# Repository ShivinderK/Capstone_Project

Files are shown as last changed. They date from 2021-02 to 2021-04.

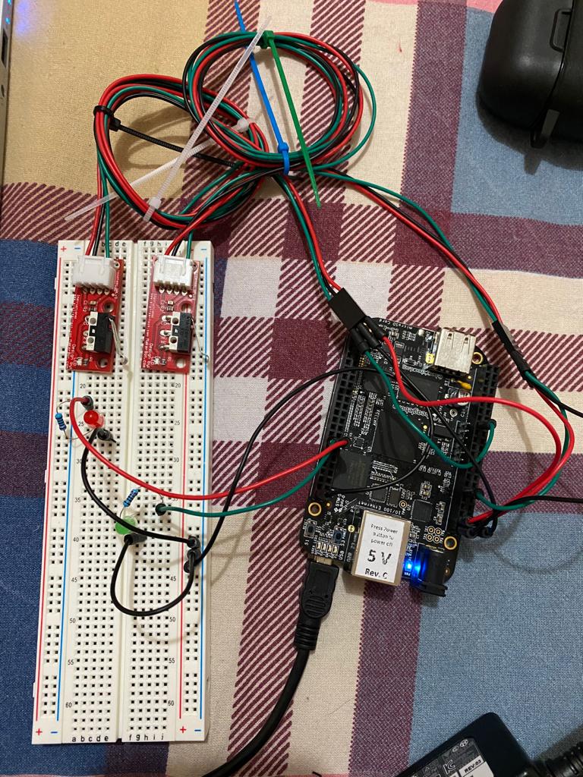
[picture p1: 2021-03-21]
Interfacing of Beaglebone black with Limit switch/Hardware connections.jpeg

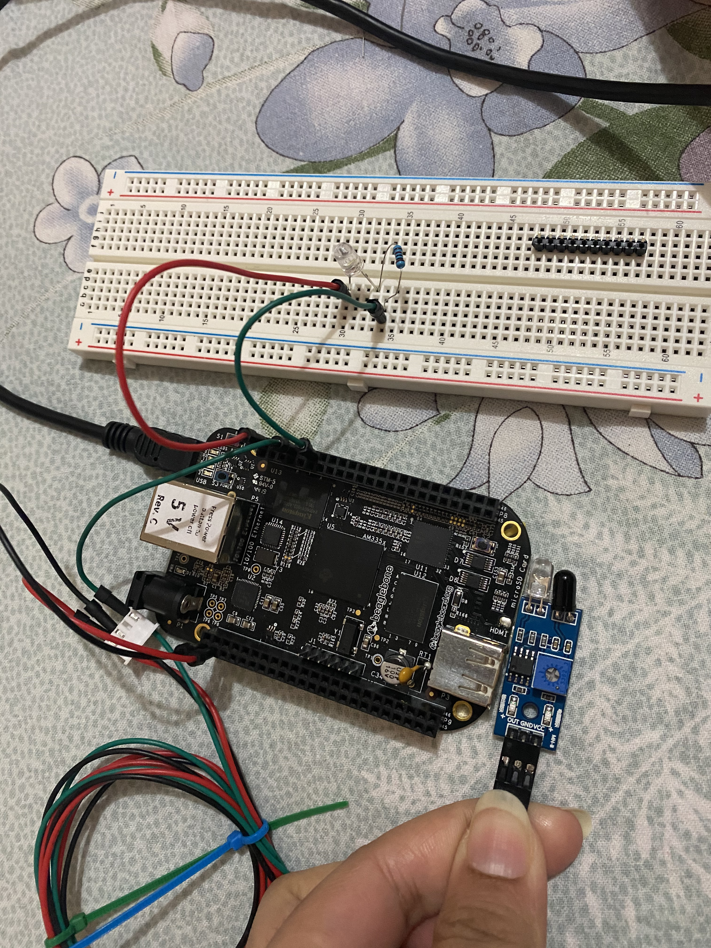
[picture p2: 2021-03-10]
interfacing PIR sensor 1/IMG-0328.jpg

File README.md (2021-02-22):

_# Capstone_Project
Group Members: Shivinder Kaur (C0751078), Dawinder Kaur (C0765505), Manpreet Kaur (C0757604), Raghav Chopra (C0772292), Gopikrishnan K. Gopalkrishnan (C0753811)

Embedded Systems and design is one of the most growing industry and at a very fast pace. We as Embedded engineers always try to make something innovative and useful for end user as an embedded application. In semester 4 , we are challenged to showcase our skills which we have learnt in past 3 semesters into a reality.  We have learnt various skills such as Working with software platform i.e eclipse ide for C  and C++. In this semester we will do coding with these platform for our final project. The another software tool which we will use in this semester is cloud computing services such as AWS or Thingspeak. Apart from that, in subjects 3025 and 3014 we worked with arduino, beaglebone black for our class assignments. That gave us an exposure to interface between these components and all the requirement to work with these MCU's. While working in labs in semster 1 and 2 we worked with basics of electronics such as power measurement , voltage regulators , ADC and DAC’ And therefore we can use that experience to implement in our capstone project.

Our project "IOT based smart garage door opener" is the upgradation of the currently used garage door openers accessed through the web. In our project an alternate garage door access provision via a keypad and LCD screen is provided, along with that key security features like sending notifications via GSM Module, Use of IR Proximity sensors to prevent any accidents and the usage of a buzzer in case any obstacle comes in between and the door remains open more than a set time period. In addition to all of the upgradations we are storing the opening and closing timings of the garage door on the cloud which will enable to user to find out any security breach. 

Added features will always demand extra components. This is the list of all the hardware components and their use in our project:

1. Beaglebone black: The main MCU in our project, all the components in our project are connected directly or indirectly to the unit.
2. Arduino Uno: Act as slave MCU in our project,  Added to our project to provide an alternate garage door access via Keypad and LCD screen.
3. L298N Motor driver: Used to drive the DC motor and to control its direction of rotation.
4. DC 6V Gear Motor: Used to open and close the garage door.
5. Microswitches: To detect the opening and closing of the door.
6. ESP32 Wifi Module: To access Wifi, since Beaglebone Board doesnt have an inbuilt wifi module.
7. Logic Level controller: To change the voltage level from 5V to 3.3V and viceversa for supplying different components.
8. IR Sensor: To detect any obstacle when the garage door is closing.
9. Buzzer: To alert the user in case an obstacle is detected or the garage door remains open for more than set time.
10.Push Button: To acknowledge the Buzzor.
11.GSM Module: To notify the user about the door opening and closing.
12.Keypad Matrix: To enter password for garage opening and enable garage closing via a key.
13.LCD Display: To display user entered password via special character and to display messages to user.
14.Power Adapter: To provide supply to Beaglebone black.
15.16GB Sd Card: To flash latest image of debian.
16.LED Light assorted kit: To notify open/close status of the garage door.
17.PCB Board: To solder all the components together
18.Resistors: To limit the flow of current or divide voltage through the circuit.
19.Spark Fun Beginners kit: For using various capacitors, diodes and other components we may need in the project.  
20.Silicon Hookup wires: To connect sensors, buzzer and other components to the main unit.
HARDWARE TESTING OF COMPONENTS
Hardware testing of components plays a vital role in the overall success of the project. Testing of components is done via measuring, taking readings, performing operations on the hardware to check its performance for the desired outputs.
Hardware testing is usually more detailed and thorough than verification. Testing is needed to ensure that every component of a system is operating as it should, and that the system is performing exactly in accordance with the specific local requirements.
In our capstone following are the components which we have tested:
Arduino Uno Board: Arduino Uno is a microcontroller board based on the  ATmega328P. It has 14 digital input/output pins (of which 6 can be used as PWM Outputs), 6 analog inputs, a 16MHZ quartz crystal , a USB connection, a power jack, an ICSP header and a reset button. It contains everything needed to support the microcontroller; simply connect it to a a computer with a USB cable power it with a AC-to DC adapter or battery to get started.
IR Sensor:R Sensors are Infrared sensors. It uses the Infrared light to detect if there is any obstacle in between the area. It has IR led which will reflect the light and the component next to IR led is a Photodiode which will receive reflected light if there is any obstacle present. The blue nob is the Potentiometer  on IR sensor , which can be adjusted to select the range. There are two small indicators on the sensor ; one indicates the sensor is on and the other one will light up when the receiver photodiode will receive light from the obstacle.The IR sensor gives digital output only in the form of 0 and 1.
IR sensor 						Arduino
Ground 							Ground
VCC								5V
Output Pin						Digital Output Pin 2
Lcd display:In our Capstone project we are using LCD to display messages for user. We are using 20*4 LCD display. It is very important to test display before we implement it in our final project. For this we checked the clear visual of characters displayed on the screen. We checked special characters on the display as well. Interfacing of Arduino with LCD was done to conduct the testing.
LCD Display 						Arduino
Ground 							Ground
VCC								5V
SDA								A4
SCL								A5
Buzzer:
Buzzer ia a device which will produce signalling noise to alert user whenever the door remains open for long time. Also, whenever there is an obstacle in between the door while closing. We are using CLT1036 buzzer which requires 4-8 v DC supply to operate. We connected our buzzer directly to Arduino and tested its performance.
Buzzer	 						Arduino
Ground 							Ground
VCC								Pin 13
L298N motor driver
The L298N is a dual H- Bridge motor driver which allows speed and direction control of two dc motors at the same time. The module can drive the DC motor that have voltages between 5 and 35V, with a peak current up to 2A. In our project we will use only one port for Dc motor.
DC motor is rotary mechanism that will convert the direct current to a mechanical movement, in our case it will open and close the garage door.
L298N	 						          Arduino
Ground 							Ground
VCC								5V
Input V								Battery 12V					
	DC Motor 						L298N
   Terminal 1						Out 1
	Terminal 2						Out 2
  GSM Module
  GSM module is used to send SMS to user in particular situations. It will be interfaced with Arduino Uno. The testing was done via connecting GSM Module to Arduino Uno

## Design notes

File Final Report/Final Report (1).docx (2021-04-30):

A Project Report

On

IOT Based Smart Garage Door Opener

Submitted by:

Dawinder Kaur (C0765505)

Manpreet Kaur (C0757604)

Shivinder Kaur (C0751078)

Gopi Krishnan K. GopalaKrishnan (C0753811)

Raghav Chopra (C0772292)

Under the guidance of

Dr. Mike Aleshams

ESE-4009 Embedded System Design Project

(January 2021 - April 2021 )

Abstract

This major project is all about the embedded systems and its applications in the real world with the help of beaglebone black and arduino software. As a result of enhanced civilization and modernization, human nature demands more comfort in their life. The person seeks ways to do things easily which saves time. So thus, the automatic gates are one of the inventions that brings comfort and ease in their daily life. Before as well people used garage doors to provide security to their vehicles but nowadays, in this modern world people need more security so that an unknown person will not access the garage door. That's why, IOT based garage doors are available now which secures the doors more accurately and people can save their entrance and exit times on the cloud along with the personal details of the vehicles. The owner will get the notification through the GSM module if any unknown person will try to open the garage door. The PIR sensor detects the vehicle at the time of opening the door and also finds the obstacle at the time of closing the door.

Acknowledgements

In our efforts towards the realization of the project work, we have drawn on the guidance of many people and we would like to express my heartfelt gratitude to all the people who helped in fulfilling the accomplishment of this project.

We would like to express my deep gratitude to Michael Vourakes, Director, Lambton College in Toronto for providing us an opportunity to study and in providing infrastructure and resources required to complete this project.

We also would like to extend our gratitude to Dr. Mike Aleshams for the unconditional support and coordination to make this project a success. We also would like to thank him for sparing time and providing necessary information patiently and providing efficient tips for debugging. His constant motivation and inspiration have led to successful completion of the project.

We also extend Dr. Takis Zourntos, Course Coordinator for Embedded System Design for critical advice and guidance without which the project would not have been possible. We also extend our gratitude to all other Professors of Lambton College in Toronto for their guidance and support in compiling the project and those people who have helped us knowingly and unknowingly for the completion of the project.

Lambton College in Toronto is a great place to study and work, largely because of supporting faculty members. Thanks to all my colleagues for supporting and encouraging our idea.

TABLE OF CONTENTS Page No.

List of Figures 5

Chapter I - Introduction 8

Overview 8

Problem statement 8

Goal and Objective 8

Scope of project 9

Outcomes and Benefits 12

Facilities and Resources 12

Procedure and Methodology 13

Chapter II - Literature Review 14

Chapter III - Requirement and Analysis 16

Hardware and Software 16

Hardware and Software Tools 17

Power Requirement 17

Block Diagram 18

Chapter IV - Design 21

Project Schematic 21

Knowing Hardware 22

Knowing Hardware and Software Tools 30

Cloud service - Thingspeak 34

PCB Design 36

Chapter V - Implementation and Test 39

Flow chart 39

Interfacing with BBB 43

Coding 66

Final Model 70

Chapter VI - Evaluation 72

Introduction 72

Minimum Requirements 72

Troubleshooting 72

Chapter VII - Conclusion 74

Future Work 74

Chapter VIII - User’s Guide 75

References 79

List of Figures

Figure No. | Description
2.1 | Circuit Diagram of Existing Project
2.2 | Block Diagram of Existing Project
3.1 | Block Diagram of Final
4.1 | Schematic Design of Project
4.2 | Beaglebone Black
4.3 | Pin Configuration of Beaglebone Black
4.4 | Arduino UNO
4.5 | IR Proximity Sensor
4.6 | SIM800L Module GSM Module
4.7 | Buzzer
4.8 | 4x4 Matrix Keypad
4.9 | L298N DC Motor Driver
4.10 | Limit Switches
4.11 | 20x4 LCD Display
4.12 | ESP32 Wifi Module
4.13 | Push Button
4.14 | DC 6V Gear Motor
4.15 | LED Lights
4.16 | Logic Level Controller
4.17 | Digital Multimeter
4.18 | Breadboard
4.19 | Jumper Wires
4.20 | General Purpose Tools
4.21 | Soldering Kit
4.22 | Thingspeak channel created for project
4.23 | Setting channel for read and write API
4.24 | Visualization in Thingspeak
4.25 | Easy EDA Introduction window
4.26 | Circuit Schematic Drawing
4.27 | Search window for components
4.28 | PCB Design for Project
5.1 | Flowchart using Webpage
5.2 | Flowchart using LCD and Keypad
5.3 | Interfacing BBB with IR Sensors
5.4 | Interfacing ESP32 with BBB
5.5 | Interfacing BBB with Motor Driver L298N and DC Motor
5.6 | Interfacing BBB with Limit switches
5.7 | Interfacing BBB with Buzzer
5.8 | Interfacing BBB with Push Button
5.9 | Interfacing BBB with Arduino
5.10 | Interfacing Arduino with LCD Display
5.11 | Interfacing Arduino with Keypad
5.12 | Interfacing Arduino with GSM Module
5.13 | Connections of Hardware Components
5.14 | Backview of the project
5.15 | Final model of our project
8.1 | Beaglebone with Adapter
8.2(a) | Uploading Code to the Wifi Module
8.2(b) | Connecting Wifi to the Wifi Module
8.3(c) | Wifi getting connected
8.3(d) | ESP32 Web Server
8.4 | Keypad and LCD

Chapter I

Introduction

Overview

This project is the modification and upgradation in the existing project of Smart garage door opener. In this project, we have used a GSM module, Beaglebone black, Arduino, Cloud service and other hardware components. The purpose of this project is to provide more security to the garage doors and also we have used one cloud service i.e., Thingspeak which saves the details of the vehicle and the status of opening and closing the door.

It has one most important feature that is also related to security, if someone tries to access the garage door by entering the password multiple times, then a notification will be sent to the owner of the garage in order to avoid any mishappening.

Problem Statement

The door plays an important role in home security. So, providing a secured garage door system for houses has become necessary. This project deals with opening and closing of garage doors by giving commands through webpage. The principle of operation behind the working of this project lies in the functioning of NodeMCU ESP12E. It works as a wifi module that provides access to the webpage through a local web server. The webpage displays one button to open and close the garage door using a relay module and DC motor. It has some limitations like the microcontroller NodeMCU ESP12E can only be used as a wifi module and also it is not an IOT based project. It has no security features. Because of all these limitations, we have decided to modify the existing project with new features like cloud service and additional security features.

Goal and Objectives

Goal

Make an IOT based smart garage system with GSM and cloud based technology running with Linux kernel by the end of April 2021.

Objective

- Connecting a host processor Beaglebone black to one of the available cloud services like thingspeak, Aws and so on.
- Interface the IR sensor which will help us to know if any obstacle blocks the garage door at the time of opening and closing.
- Configuring the wifi capabilities to connect cloud service.
- Send a notification if an unknown person tries to access the door by entering the wrong password three times.

Scope of the project

Deliverable

- This project will access the garage door via webpage as well as keypad and LCD for opening and closing.
- Transfer all the data to the cloud service.
- Generate a PCB design for the project.
- Intimate about the door activity via SMS services through cloud services.
- Plug and Play the project that is the smart garage door should function without the help of any other device or laptop to execute the codes written and get the exact output.

Milestones

S.no. | Task Title | Start Date | End Date | Person In-charge
1 | Project Proposal | 27-jan-2021 | 12-feb-2021
2 | Deciding and ordering hardware components | 13-feb-2021 | 15-feb-2021 | Gopi Krishnan
3 | Testing hardware components Part 1 | 16-feb-2021 | 22-feb-2021 | Raghav Chopra
4 | Testing hardware components Part 2 | 16-feb-2021 | 22-feb-2021 | Manpreet Kaur
5 | Designing Schematic Diagram | 23-feb-2021 | 26-feb-2021 | Shivinder Kaur
6 | Interfacing BBB with IR sensor (to detect the status of garage) | 27-feb-2021 | 5-march-2021 | Dawinder Kaur
7 | Interfacing WIFI Module ESP32 with BBB | 27-feb-2021 | 5-march-2021 | Shivinder Kaur
8 | HTML coding for web page | 6-march-2021 | 10-march-2021 | Dawinder Kaur
9 | Interfacing BBB with Motor Driver L298N and connecting it to DC motor | 11-march-2021 | 15-march-2021 | Gopi Krishnan
10 | Interfacing of Limit Switch with BBB | 15-march-2021 | 19-march-2021 | Raghav Chopra
11 | Interfacing BBB with IR sensor (to detect obstacle) | 15-march-2021 | 19-march-2021 | Manpreet Kaur
12 | Interfacing Buzzer with BBB | 20-march-2021 | 26-march-2021 | Raghav Chopra
13 | Interfacing Button with BBB | 23-march-2021 | 28-march-2021 | Shivinder Kaur
14 | Interfacing Cloud services with ESP32 | 28-march-2021 | 2-april-2021 | Dawinder Kaur
15 | Interfacing Arduino with BBB | 28-march-2021 | 2-april-2011 | Gopi krishnan
16 | Interfacing LCD display with arduino | 3-april-2021 | 9-april-2021 | Manpreet Kaur
17 | Connecting Keypad with arduino | 3-april-2021 | 9-april-2021 | Raghav Chopra
18 | Interfacing Arduino with GSM Module | 10-april-2021 | 16-april-2021 | Gopi Krishnan
19 | PCB design using particular software | 10-april-2021 | 16-april-2021 | Manpreet Kaur
20 | Zero PCB Implementation Part 1 | 17-april-2021 | 23-april-2021 | Shivinder Kaur
21 | Zero PCB implementation Part 2 | 17-april-2021 | 23-april-2021 | Dawinder Kaur
22 | Final Report | 24-april-2021 | 25-april-2021
23 | Final Presentation | 27-april-2021 | 28-april-2021

Limitations

- When the user enters the wrong password to open the garage door more than 3 times then the owner will get notification but the LCD and keypad does not get locked. The user still can access them.
- If the owner forgets the password then there is no option to reset the password directly using keypad and LCD.

Outcomes and Benefits

- This project is powered up with the power adapter so no need to worry about the power unless there is no electricity in the house.
- If due to some reason the owner will not be able to open the door by using a keypad then he/she can access it by using cloud service.
- It could be an upgrade to the existing project.
- It will help to save the details of the door status at the time of opening and closing to the cloud service which the owner can review later on.

Facilities and Resources

Laboratory

- As we have our classes online so we were not able to access the Embedded Systems Lab of our college. So we created a miniature laboratory at our own places to do all the work on the project.
- Soldering stations, Digital Multimeters, Linux or PuTTy installed PCs and all the other required components were available at our homemade labs.

Intellectual Resources

- Data sheets of GSM module, Beaglebone black, Arduino and other hardware components.
- Forums of Beaglebone, Element14 and components101 communities.
- Exploring Beaglebone tools and techniques for building with Embedded Linux (Second Edition) from Derek Molloy.

Procedure and Methodology

- Getting the hardware requirements ready and ordered for the project sideways testing the components and understanding their working as they keep on arriving.
- Install and update the devices such as the Beaglebone with the latest image OS in order to get to use some of the latest features available in terms of device trees and drivers.
- Upon the getting the testing results positive and approved move and design the circuit schematic using software like EasyEDA, Fritzing, KiCad or Eagle, etc.
- Installation of various libraries which will make our task of controlling the pins of Beaglebone easy and communication between peripherals and sensor simpler.
- Keeping the schematic in mind gets the connection ready for the interfacing in part as this will help us to know in case we go wrong or if the system is not working at some points.
- We start with the interfacing of BBB with IR to detect the status of the garage.
- To make the data available on the cloud service we need to establish a wired connection between ESP 32 and BBB and send the appropriate data to the cloud and make it visible to the user.
- After that, interface all the hardware components with each other.
- At the end of all the interfacing we will integrate them and check if we get the desired functionality as mentioned in the proposal.
- In order to minimize the amount of wiring we must generate the PCB design. The PCB could be designed with the same software that we may have used in making the schematic on the software in step iii).
- Solder the devices on the PCB and test for the final demonstration of the project.
- Make the project run in such a way that when powered on the program should auto-run without the help of any sort of connection with laptop or any external devices.

Chapter II

Literature Review

Wifi Based Smart Garage Door Opener

This project deals with opening and closing of garage doors by giving commands through webpage. The principle of operation behind the working of this project lies in the functioning of NodeMCU ESP12E. It works as a wifi module that provides access to the webpage through a local web server. The webpage displays one button to open and close the garage door using a relay module and DC motor.

Circuit Diagram:

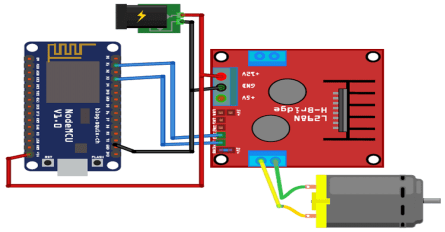
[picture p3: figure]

Fig.2.1 Circuit Diagram of Existing Project

Block Diagram:

Fig.2.2 Block Diagram of Existing Project

Working:

The working principle of the project is giving commands through a web page displaying a message about garage door “open and close” status. So when the garage door is closed then the message is displayed as “The Garage Door is closed” and the OPEN button is shown on the screen. The Node MCU ESP12E is programmed accordingly using an Arduino IDE by providing a wifi username and password in code. When the user opens the webpage using the IP address from the serial monitor window the web page opens. When the user clicks on the open or close button the message goes to Node MCU which passes the command to the relay module to rotate the DC motor “clockwise or anticlockwise” which helps in opening and closing the garage door.

CHAPTER III

Requirement and Analysis

Hardware and Software

In this project, we are using hardware and software components along with the hardware and software tools so that we will get the proper output. Below, we have attached the list of hardware and software components and also the tools which we have used in our project.

Hardware components :

1. Arduino Uno
2. Beaglebone Black
3. ESP32 wifi module
4. 4x4 matrix keypad
5. 20x4 LCD Display
6. SIM800L Module GSM/GPRS
7. Power Supply
8. IR proximity sensors
9. Buzzer Electronic alarm
10. Push button
11. MicroLimit switch
12. DC Motor
13. L298N Motor Driver
14. SanDisk SD card 16 gb
15. Logic level controllers
16. PCB Board
17. 5mm LED light assorted kit

Software components:

1. Latest image of debian for beaglebone black
2. Amazon Web Services or ThingSpeak or any other free IoT service provider.
3. C/C++ Programing
4. HTML programming

Hardware and Software Tools

Hardware Tools:

1. Multimeter
2. Breadboard
3. Jumper Wires/ Silicon hook up wires
4. General purpose tools
5. Soldering Kit
6. Laptop or host machine

Software Tools:

1. EasyEDA for PCB and schematic design
2. Eclipse IDE for programming
3. PuTTy software
4. Compiler
5. Debugger
6. Assembler
7. Arduino IDE

Power Requirement

We are providing a sufficient amount of power to get the system working and performing all the tasks. Thus, looking at the requirement for our project we find that we have two major power consuming components which are:

1. Beaglebone Black – 2 A @ 5V

2. Arduino based GSM Shield – 2 A @ 5V

So, estimated power requirements for full product assembly will be approximately 4V @ 4A for smooth and interrupt free operation. As most of the hardware components that we want to use for the project and when we look at the pin out diagram of the same, we realise that we can power them up directly from the Beaglebone thus no extra power supply is required for them.

Block Diagram

For the final solution, we will implement the project as we have discussed in the second solution but with some modifications. We will add a GSM module in the project which will be connected with Arduino. This module will be used for sending notifications to the user via SMS in case the door remains open. Also, the keypad will be used to enter a password to open the door but for closing the door we will just need to press enter key.

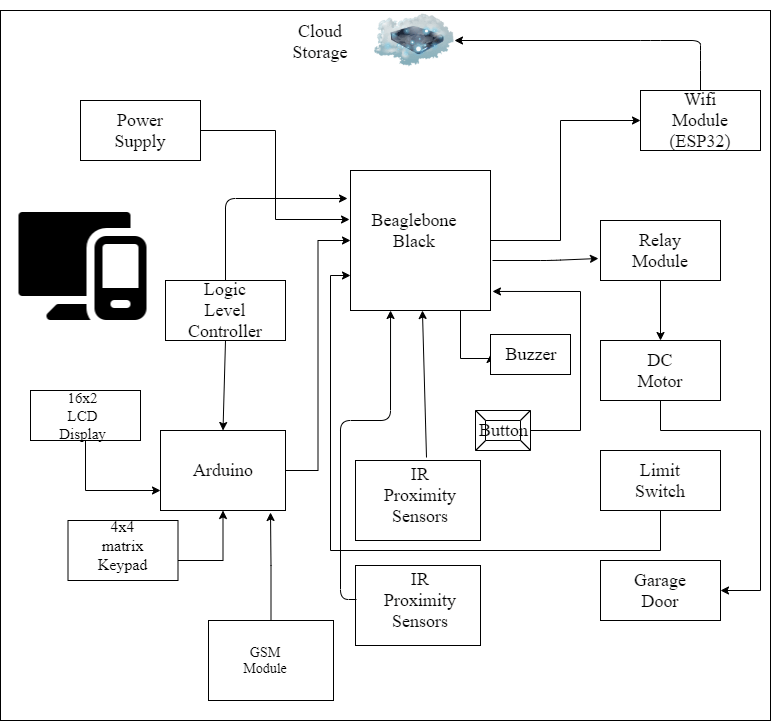
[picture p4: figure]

Fig 3.1 Block diagram for the final solution

Features:

- Using Beaglebone as the main microcontroller which has high processing speed and more advanced features.
- Using Arduino as a slave device which is supporting the alternate solution of opening and closing the door.
- The project is IoT based as it is connected to Wifi for cloud storage.
- IR Proximity Sensors will be used to detect any object in between the garage door while closing.
- Use of a buzzer if the door remains open for a long time.
- Also a GSM module has been added which will notify the owner via SMS that the door remained open.

Chapter IV

Design

Project Schematic

Fig 4.1. Schematic Design for the project

Above figure shows the schematic capture for the project which will help us wire the same. To draw the schematic, we use EasyEDA software. EasyEDA is a free open-source platform and is best suited for beginners in schematic capture. As we can see in this schematic how the hardware components get connected with the Beaglebone black. All Beaglebone Boards have the same pin configuration. At the later stage of the project, we used this schematic and converted it into the PCB Layout which we can use to get PCB manufactured for the project. Before moving on further let us first discuss and know the hardware in detail which will help us in programming the system and reason for our connection.

Knowing Hardware

Beaglebone Black

The Beaglebone black is a low cost, open hardware and expandable computer launched by a community of developers from Texas Instruments. It consists of a large amount of input and output pins and also it has on board interfaces which enables the devices to connect smoothly with the beaglebone black.

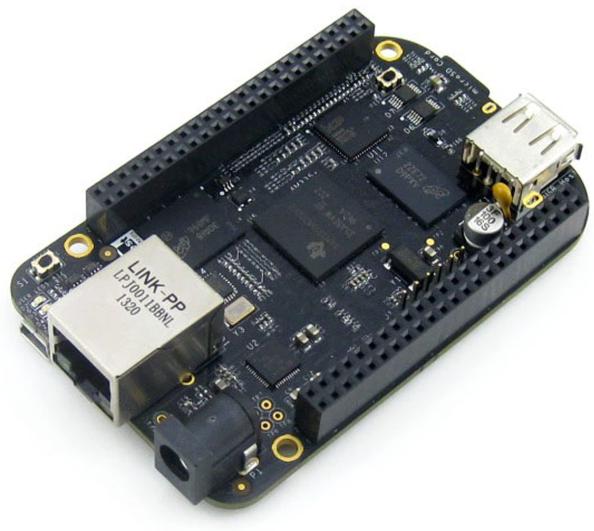
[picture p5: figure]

Fig 4.2. Beaglebone Black

Beaglebone Black has so many technical specifications and also it has a large number of GPIO I/O pins. It is an open source hardware technology which gives options to the manufacturer to integrate ARM technology for developing cloned beaglebone development boards and also it provides options to install a wide range of android and linux based operating systems.

Pin configuration of Beaglebone Black:

It has two headers P8 and P9 and both headers have 46 pins. Also, it has GPIO pins as well which we can use at the time of interfacing with other hardware components.

Fig 4.3. Pin Configuration of Beaglebone Black

Arduino Uno

The Arduino UNO is an open source microcontroller board which is based on the microchip ATmega328P (for Arduino UNO R3) or microchip ATmega4809 (for Arduino UNO wifi R2) microcontroller by Atmel and was the first USB powered board developed by Arduino.It contains everything needed to support the microcontroller, simply connect it to a computer with a USB cable or power it with a AC-to-DC adapter or battery to get started.

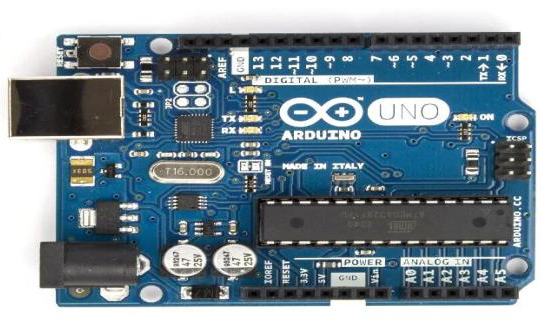
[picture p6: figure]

Fig 4.4. Arduino UNO

IR Proximity Sensors:

In our project we are using IR sensor EK1254 which is an obstacle detecting sensor. We will place this sensor on the garage door to avoid any collision while the door will be closing. This module can be directly connected to beaglebone black. It can be connected to both 5V and 3.3 V microcontrollers.

The module does not require to contact the object to detect it; it detects within the distance between 2-30 cm. They are capable of detecting motion in presence or absence of the light almost with the same reliability.

The figure shows the IR sensor. It has a transmitter and receiver to detect any obstacle.

Fig 4.5. IR Proximity Sensors

SIM800L Module GSM GPRS

In our project we want to notify users via SMS, if the garage door remains open for a long time and sends an alert message. For this purpose we will use the SIM800L GSM module. It is a small miniature cellular module which allows for GPRS transmission, sending and receiving messages. Here are the specifications of this module:

- Quad-Band GSM 850/900/1800 / 1900MHz
- GPRS multi-slot class 12/10
- GPRS mobile station class B
- GSM 2/2 +FM frequency between 76 MHz and 109 kHz adjustable by step 50AT command set support (3GPP TS 27.007, 27.005 and augmented by SIMCOM AT)
- Class 4 (2W at 850 / 900MHz)
- Class 1 (1 W at 1800 / 1900MHz)
- Serial interface
- SIM card interface 3 V / 1.8 V

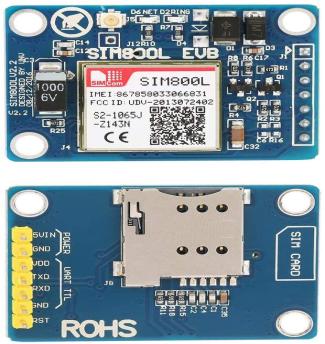
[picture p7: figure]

Fig 4.6. SIM800L Module GSM GPRS

Buzzer

To alert the user about obstacles we need an actuator , for this purpose we are using a buzzer and this will be connected to beaglebone black. For our project we are using Cylewet CLT1036. It requires <25mA and 4-8 voltage to operate.

Fig 4.7. Buzzer

4X4 Matrix Keypad

Matrix keypads are the kind of keypads you see on cell phones, calculators, microwaves ovens, door locks, etc. Membrane keypads are made of a thin, flexible membrane material. They do come in many sizes 4×3, 4×4, 4×1 etc. Regardless of their size, they all work in the same way.Let’s take 4×4 keypad as an example. It has a total of 16 keys. Beneath each key is a special membrane switchAll these membrane switches are connected to each other with a conductive trace underneath the pad forming a matrix of 4×4 grid.

Fig.4.8. 4X4 Matrix Keypad

L298N DC Motor Driver

L298N Motor Driver interface with beaglebone black which controls both speed and spinning direction of two DC motors.

This can be achieved by combining these two techniques.

- PWM (Pulse Width Modulation) – For controlling speed
- H-Bridge – For controlling rotation direction

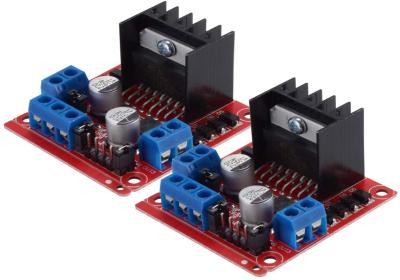
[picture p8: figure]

Fig.4.9 L298N DC Motor Driver

Limit Switches

The micro limit switch, or micro switch, is a limit switch commonly found on control circuits. In our project we will use these switches to sense motion and to open and close the door with the actuators.In our project we will use PChero part number iS008 switch.

Fig.4.10 Limit Switches

20X4 LCD Display

In our project we will notify the user via lcd display whenever the user will enter the wrong password. To display certain messages to notify the user for access granted or access denied. For our project we are using 20*4 LCD display module. It can show 20 characters in one row which is perfect to display a small message to the user. This specific product includes a serial interface adapter and therefore no need to buy an extra adapter. Less I/O ports are occupied, only four - VCC, GND, SDA (serial data line), SCL (serial clock line). and thus no connections are required.

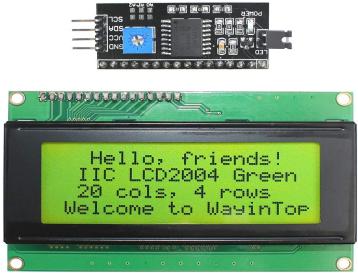
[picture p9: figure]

Fig.4.11 20X4 LCD Display

ESP32 Wifi Module

As we have discussed that our project is going to be IOT based, for that we need internet connection. As we are using beaglebone black, which doesn’t have any internal wifi module. Therefore, we will use a separate Wifi Module for internet connectivity. For this purpose we are using the ESP32 wifi module. This module can be used for low power sensors networks. ESP32 also integrates a wealth of peripherals, including capacitive touch sensors, Hall sensors, low noise sensor, SD card interface, Ethernet interface, high-speed SDIO / SPI, UART, I2S and I2C.

Fig.4.12 ESP32 Wifi Module

Push Button

In our day to day life we encounter various push button switches such as on medical equipment, automated production lines, and communication equipment. It is a very simple component, but because it controls the entire control circuit, it is also known as “Control Switch”.

The push button is usually used to turn on and off the control circuit, and it is a kind of control switch appliance that is widely used. It uses electrical automatic control circuits to manually send control signals to control contactors, relays, electromagnetic starters, etc.

Fig.4.13 Push Button

DC 6V Gear Motor

DC gear motor has an integrated M3*55mm threaded rod as its output shaft. It has a series of gears, which in turn creates more torque. The range of driver voltage between 5 to 35V and driver current is 2A. Its maximum motor supply current is 2A and maximum power is 25W. The revolutions per minute of the DC motor is 150RPM.

Fig.4.14 DC 6V Gear Motor

5mm LED Light

In this project, we are using LEDs for various purposes like to show the status of opening and closing the garage door and also we have LEDs which are connected to the IR proximity sensor in order to detect any obstacle.

Fig.4.15 5mm LED Lights

Logic Level Controllers

In our project, we have used logic level controllers to shift the voltage level between Beaglebone Black and Arduino because as we know Beaglebone Black needs 3.3V and Arduino operates at 5V. This controller converts the 3.3V to 5V so that Beaglebone and Arduino can communicate smoothly.

Fig.4.16 Logic Level Controller

Knowing Hardware and Software Tools

Hardware Tools

- Multimeter : It is one of the most important measurement and testing devices in any project. It is used popularly for keeping a track of current, voltage, resistance, and other values, all of which are very critical for the safe and balanced working of the project. It plays a big part in component testing as well. There are two types of multimeter in the market. First is analog multimeter and the second is digital multimeter, but in our project we are using digital multimeter because of its better accuracy.

Fig 4.17 Multimeter

- Breadboard: It is the base of any project. It is popularly used for making a model to check the proper functioning during design before soldering the components.

Fig4.18 Breadboard

- Jumper Wires: Classified as male to male, male to female and female to female, It is another prototype tool which is used for establishing connections on the breadboard for designing a prototype model.

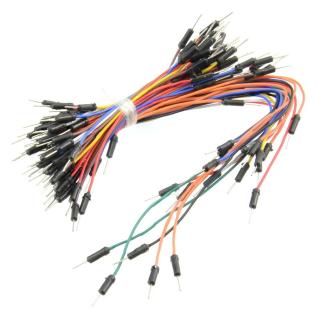
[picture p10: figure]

Fig 4.19 Jumper Wires

- General purpose tools: For designing and modeling of the project many general purpose tools will be required. These tools are used during the project design and implementation. For ex: A wire cutter, wire stripper, ruler, measuring tape etc.

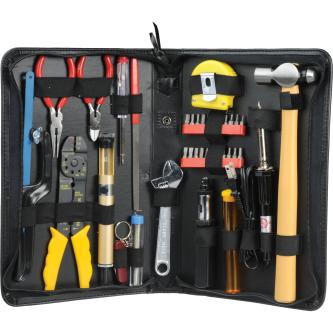
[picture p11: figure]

Fig 4.20 General Purpose Tools

- Soldering Kit : It is a tool used by hobbyists, students and engineers for establishing permanent connections between various components. In this project it is used for soldering various hardware components in the final stages.

Fig.4.21 Soldering Kit

- Laptop or a host machine: From the beginning of the project to the demonstration with a plug and play model, a laptop with all the required softwares installed and with a stable internet connection is a must. Writing the code, producing a file for the microcontroller, simulation and design of the project and much more is impossible without a laptop.

Software Tools

- EasyEDA for schematic and PCB design : It is a linux operating systems based open source schematic and PCB designer. It allows users to model and document their prototypes. It enables the analysis and experimentation of the design before making a permanent circuit. The software facilitates a project to be viewed and exported in three designs that is breadboard, PCB and schematic.
- Eclipse IDE : It is one of the most popular Integrated Development Environment used for programming in languages like C, C++, Java etc. In this project it plays an integral part in the development of software. Its workspace enables users to handle all the projects at the same place. The testing and debugging, for the identification of any bugs is relatively easy in this IDE.
- Compiler: The source code is written in a high level programming language. The compiler converts the source code written into a machine level language.
- Debugger: It is a computer program which helps in testing and finding bugs(errors) in a software code. It plays an important part in pointing errors and its effective rectification.
- Assembler: It converts the assembly language into a binary machine code which can be processed by the CPU.
- Linker: It is a computer program that links one or more object files and combines them into a single executable file, library file or object file.
- Geany Text editor: It is a lightweight GUI text editor based on Scintilla and GTK. It is now ported to almost all operating systems like Linux, Windows, Mac, Solaris etc. The advantage of this editor is its GUI, short loading time,support cross platform and flexibility.
- Arduino IDE: It is an open source cross platform IDE that facilitates to write code and upload it to the board. It can be used with any arduino boards making that its biggest advantage. It can be used with windows, Mac and Linux operating systems. In this project it is used for the programming of the arduino board.
- Teraterm: It is an open source and free application which emulates computer terminals. In other words it is a serial terminal monitor. It supports telnet, SSH and ensures serial port connections. It has a macro scripting language and ensures high terminal standards.

Cloud Service - Thingspeak

ThingSpeak is an open-source Internet of things (IoT) application and API. It uses the HTTP and MQTT protocol to store and retrieve data over the internet or via a Local Area Network (LAN). It can generate instant live data visualizations and send notifications using web services. ThingSpeak allows users to aggregate, visualize, and analyze live data streams in the cloud. It has integrated support of MATLAB from MathWorks. User can send:

- Data to ThingSpeak from their devices
- Create instant visualization of live data
- Send alerts.

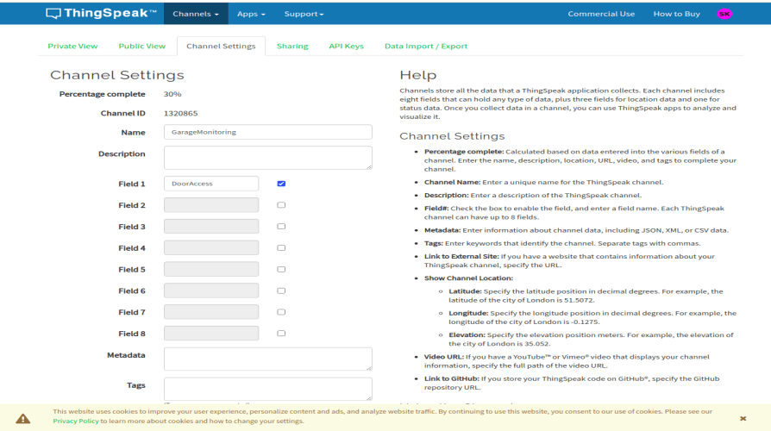
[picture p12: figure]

Fig.4.22 Thingspeak channel created for the project

Fig.4.23 Setting Channel for Read and Write API

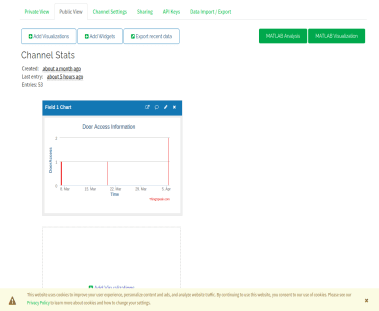
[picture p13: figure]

Fig.4.24 Visualization in Thingspeak

PCB Design

PCB design for our project is done on EasyEDA. It is an easier and powerful online PCB design tool that allows to design and share projects. Printable PCB layer image output is also supported in PDF, PNG, and SVG formats. Circuit designing is completed by using manual routing. We used the same schematics which we used to understand how we can draw out the connection between the Beaglebone Black and Sensors/ Devices.

Easy EDA has a large user contributed library thus people can easily find almost any component which they require for the project. To get a successful PCB design from a given schematic one just needs to be sure that the component has a suitable footprint else the design wouldn’t be possible. One more advantage is, it can support other software libraries and schematics which includes Altium, EAGLE, LTspice, and DXF.

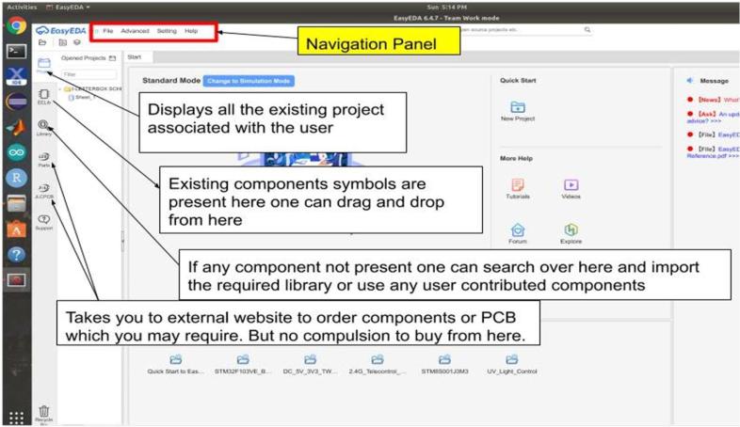
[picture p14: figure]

Fig.4.25 EasyEDA Introduction window

Fig.4.26 Circuit Schematic Drawing

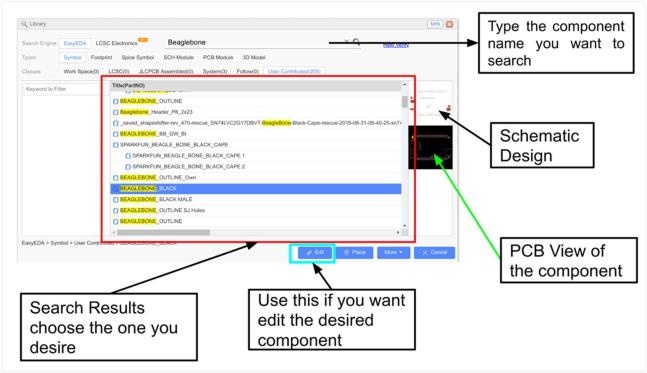
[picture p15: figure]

Fig.4.27 Search Window for Components

Upon following the user manual guidelines for this software, we finally drew the PCB design for our project as shown below. Through this software one can also generate the BOM (Bill of Material) for the project which will give you a list of components to be purchased to make this project. This BOM can be used as a checklist when one goes to the market to get the components.

Fig.4.28 PCB Design for the project

Chapter V

Implementation and Test

Flow Chart

1.Flow Chart for IoT based smart garage door opening and closing using Webpage:

Explanation:

First the local server is started and the IP address is entered to open the login page for the user. If the correct login id and password details are given the provision will be provided to open or close the garage door. If the user enters the incorrect details the login page access will be denied. Once the correct login details are entered a choice will be given for opening or closing the door. If the user chooses the open icon, an input will be given for the relay to operate which will in turn enable the rotation of the dc motor and the garage door will be opened. After the door is opened a notification is sent to the user with the help of a GSM module and the door opening time gets recorded in the cloud. If the user forgets to close the door for a set period of time, a notification will be sent to the user to remind them that the door is not closed. The next stage of this project is if the choice is made by the user for closing the garage door. In our project for ensuring a secure and safe closing of the door an IR proximity sensor along with limits switch is used. In case an obstacle for example: a kid comes in between when the door is being closed the two components prevent the door from closing. If an obstacle is detected, a buzzer will be activated which will notify the user of the potential occurrence of a danger. Once the obstacle is cleared by the user, the closing of the door will be possible by pressing the key of the keypad. If an obstacle is not detected it will close normally as designed. Once the door is closed, a message will be sent to the user to inform the user about the closing of the door and a record of the door closing time will also be stored in the cloud.

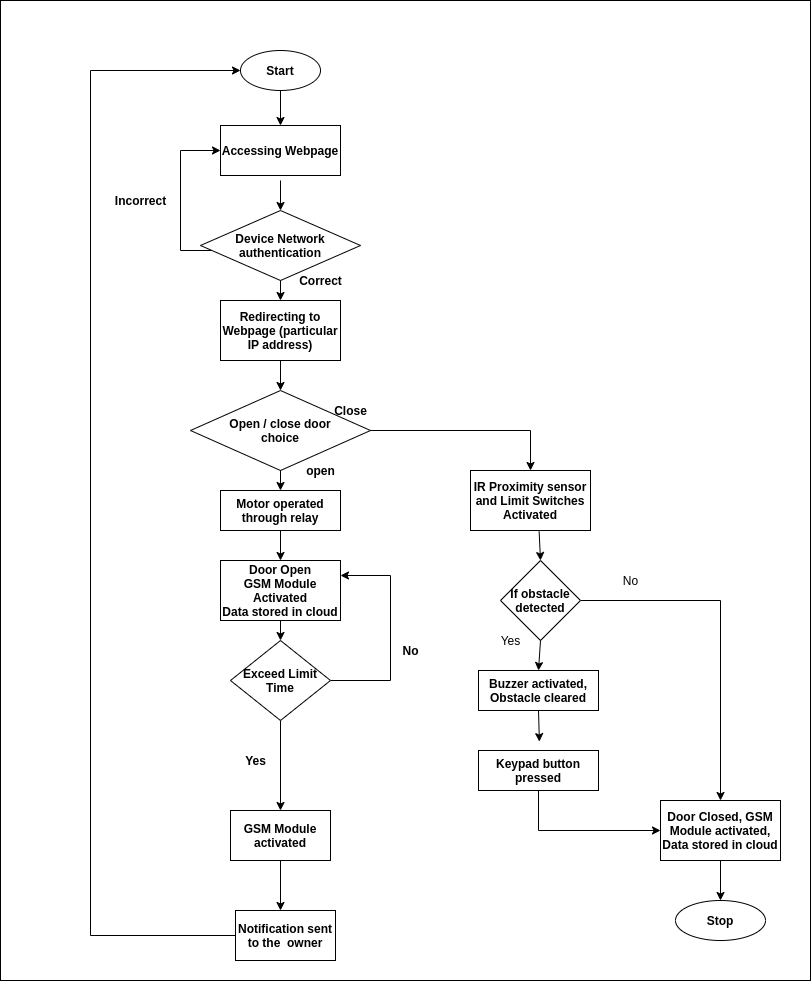
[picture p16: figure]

Fig5.1. Flowchart using Webpage

2.Flow Chart for IoT based smart garage door opening and closing using keypad and LCD screen:

Explanation:

At the initial stage of the flow chart, when the vehicle will come to enter the garage, the keypad on the door will ask the password to open the door. If the password entered by the user is correct then the motor drivers will start operating through the relay module and the door will open but if the password will be incorrect then the LCD display will show the “ACCESS DENIED”. If a wrong password is entered more than three times via Keypad, A message will be sent to the user via GSM module to notify incorrect password entry, thus it enhances the security feature of the project. After this stage, all the information regarding the vehicle user and the timing will be saved in the cloud for future use or for security purposes as well. If the door will open for so long then the GSM module will activate and it will send the notification to the user through SMS that the door is open, if not then a key is used to close the door. After that, the IR proximity sensor and the limit switch will start functioning and they will detect the obstacle at the time of closing the door. If they sense any obstacle, then the buzzer will start beeping and the door will remain open and then a button will be pressed to close the door again or the closing will be pressed. If there will be no object or obstacle then the door will close and all the data regarding the entry and exit of the object will be saved in the cloud storage. GSM module will enable at the closing of the door as well, if there will be any suspicious activity that will happen to inform the user.

Fig.5.2 Flowchart using LCD and Keypad

Interfacing with BBB

- Interfacing of Beaglebone black with IR Proximity sensors

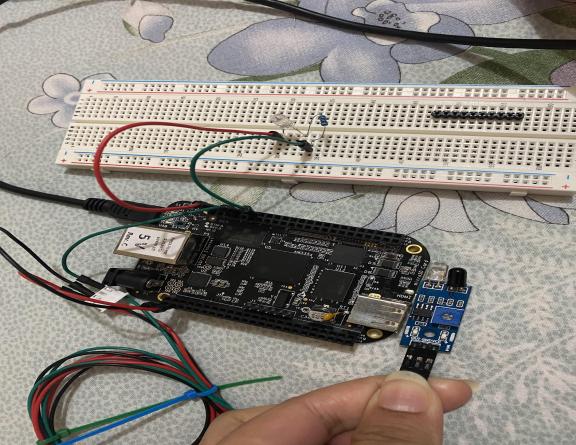
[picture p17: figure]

Fig.5.3 Interfacing of BBB with IR Proximity sensors

Above figure shows how IR proximity sensor is interfaced with Beaglebone black and also one LED is connected only for the demonstration purpose. We have connected the SIG/OUT pin of IR sensor with the GPIO_66 pin of P8 header of Beaglebone Black and also VCC pin to 3V and Ground pin connected to the Ground pin of BBB.

Code:

#include <stdio.h> //includes standard I/O header files
#include <iobb.h> //includes GPIO I/O header files
#include <unistd.h> //includes POSIX API library for adding delay in operation
#define IRoccupancy 8,8 // PIR sensor connected to pin 8 of header P8
#define LEDpin 8,12 //LED is connected to pin 12 of header P8
int main(void) // main function
{
iolib_init(); // initializing GPIO I/O library
iolib_setdir(IRoccupancy, DigitalIn); //setting GPIO pin for output
iolib_setdir(LEDpin, DigitalOut);
while(1) //continuous loop
{
if (is_high(IRoccupancy)) //if pin 8 of header is low
{
printf("Garage is Unoccupied \n"); //print on terminal
pin_low(LEDpin); //LED will not glow
usleep(1200000); //delay operation
}
if (is_low(IRoccupancy)) // if pin 8 of header is high
{
printf("Garage is Occupied \n");
pin_high(LEDpin); //LED will glow
usleep(1200000);
}
}
iolib_free(); //end of program (freed library resources)
return(0); //return a value
}

- Interfacing of ESP32 Wifi Module with BBB

Fig.5.4 Interfacing of ESP32 wifi module with BBB

Above figure depicts the interfacing of BBB with ESP32 wifi module and also we have used two LEDs for the demonstration purpose. The connections between both the components are explained below:

Connections of Beaglebone Black and LEDs

- Green LED is connected to P8.11 of Beaglebone Black.
- Red LED is connected to P8.12 of Beaglebone Black.
- Resistors of 330k Ohms have been used in between both the LEDs.
- GND has also been connected.

Code:

#include <iobb.h>
#include <stdio.h>
#define GreenLED 8,16
#define RedLED 8,15
#define Gon 8,11
#define Ron 8,12
int main(void)
{
iolib_init();
iolib_setdir(GreenLED,DigitalIn);
iolib_setdir(RedLED,DigitalIn);
iolib_setdir(Gon,DigitalOut);
iolib_setdir(Ron,DigitalOut); //iolib_delay_ms(500);
while(1)
{
if (is_high(GreenLED))
{
printf("Green LED is ON \n");
pin_high(Gon); iolib_delay_ms(500);
}
else (is_low(GreenLED))
{
printf("Green LED is OFF\n");
pin_low(Gon); iolib_delay_ms(500);
}
if (is_high(RedLED))
{
printf("Red LED is ON \n");
pin_high(Ron); iolib_delay_ms(500);
}
else (is_low(RedLED))
{
printf("Red LED is OFF \n");
pin_low(Ron); iolib_delay_ms(500);
}
}
iolib_free();
return(0);
}

- Interfacing BBB with Motor Driver L298N and connecting it to DC motor

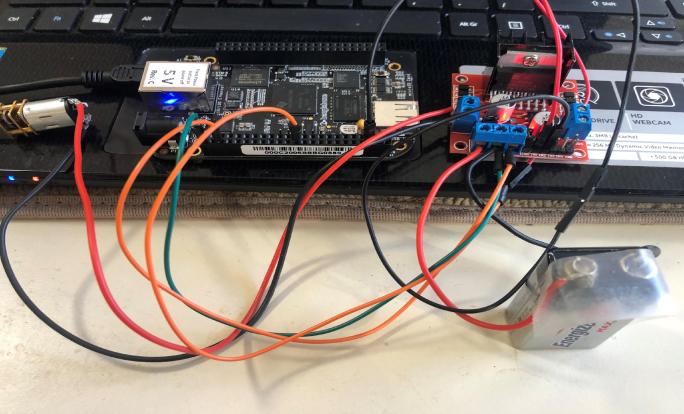
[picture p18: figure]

Fig.5.5 Interfacing BBB with Motor Driver L298N and connecting it to DC motor

Above figure shows how BBB is connected to the L298N motor driver and connecting to the DC motor. We have used Pin no. 23 and 41 of P9 header for the interfacing. The connections are explained below:

Motor Driver 12V to Battery +

Motor Driver Ground to Battery -

Motor Driver Ground to Beaglebone DGND

Motor Driver Input 1 to Beaglebone P9.41

Motor Driver Input 2 to Beaglebone P9.23

Motor Wire 1 to Motor A+

Motor Wire 2 to B+

Code:

#include <stdio.h> // Standard Input Output Library
#include <iobb.h> //GPIO Library
int motor1 = 23; //Motor 1 Pin
int motor2 = 41; //Motor 1 Pin
int port9 = 9;//Defining variable for port 9
int port8 = 8;//Defining variable for port 8
char motion; //Variable to take input
int main(void)
{
iolib_init(); //initialize the iobb library
iolib_setdir(port9, motor1, DigitalOut);//setting the pin as Digital out
iolib_setdir(port9, motor2, DigitalOut);//Setting the pin as Digital out
while(1)
{
printf("Enter 0: Stop, 1: CW, 2: CCW: ");//print message to the user
motion = getchar();//Read one character input
if(motion == '1') //if input is 1
{
printf("Motor in CW direction\n"); //print message to the user
pin_high(port9, motor1); //INA pin high
pin_low(port9, motor2); //INB pin low
}
else if(motion == '2') //if input is 2
{
printf("Motor in CCW direction\n");//print message to user
pin_low(port9, motor1); //INA pin low
pin_high(port9, motor2); //INA pin high
}
else if(motion == '0') //if input is 0
{
printf("Motor Stopped\n"); //print message to user
pin_low(port9, motor1); //INA pin low
pin_low(port9, motor2); //INB pin low
}
}
iolib_free(); // Release all GPIOs to default status
return(0);
}

- Interfacing of Limit Switch with BBB

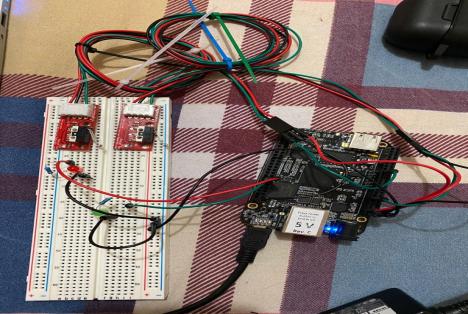
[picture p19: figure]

Fig.5.6 Interfacing of Limit Switch with BBB

The above figure illustrates the connection between the BBB and limit switches. In our project, we are using limit switches to detect the status of the garage door and if that door opens too long and we can use limit switches manually to close the door.

- Connected green led to the pin 16 of header P8
- Connected red led to the pin 15 of header P8
- Connected limit switch for door open to the pin 30 of header P9
- Connected limit switch for door close to the pin 12 of header P9

Code:

#include <iobb.h> //includes GPIO I/O header files
#include <stdio.h> //includes standard I/O header files
#include <unistd.h> //includes POSIX API library for adding delay in operations
#define GreenLED 8,16 //Green led connected to pin 16 of header P8
#define RedLED 8,15 //Red led connected to pin 15 of header P8
#define LMcheckDoorOpened 9,30 //Limit switch for door open connected to pin 30 of header 9
#define LMcheckDoorClosed 9,12 //Limit switch for door close connected to pin 12 of header 9
int main(void) // main function
{
iolib_init(); // initializing GPIO I/O library
iolib_setdir(GreenLED, DigitalOut); //setting GPIO pin for Output
iolib_setdir(RedLED, DigitalOut);
iolib_setdir(LMcheckDoorOpened, DigitalIn); //setting GPIO pin for Input
iolib_setdir(LMcheckDoorClosed, DigitalIn);
while(1) //continuous loop
{
if (is_low(LMcheckDoorOpened)) //if pin 30 of header is low
{
printf("Door is open \n"); //print on terminal
pin_high(RedLED); //Red LED will glow
usleep(1200000); //delay operation
}
else if (is_high(LMcheckDoorOpened)) //if pin 30 of header is high
{
pin_low(RedLED); //Red LED will not glow
}
if (is_low(LMcheckDoorClosed)) // if pin 12 of header is low
{
printf("Door is Closed \n");
pin_high(GreenLED); //LED will glow
usleep(1200000);
}
else if (is_high(LMcheckDoorClosed)) //if pin 12 of header is high
{
pin_low(GreenLED); // LED will not glow
} }
iolib_free(); //end of program (freed library resources)
return(0); //return a value
}

- Interfacing Buzzer with BBB

Fig.5.7 Interfacing Buzzer with BBB

In this interfacing we have used IR sensor and push button as well. The purpose of using IR sensor is to detect any obstacle and push button is to disable the buzzer manually. The connection between all the components explained below:

Connections of Buzzer with Beaglebone Black:

- The positive (+ve) pin of Buzzer is connected with pin 23 of header 9 of beaglebone black.
- The negative (-ve) pin of Buzzer has been grounded.

Connections of IR Sensor with Beaglebone Black:

- The output pin of IR Sensor is connected to pin 7 of header 8 of beaglebone black.
- Ground pin of both the components has been connected to each other.
- 5V power supply has been provided to the Vcc pin of IR Sensor.

Connections of Push Button with Beaglebone Black:

- One pin of the push button is connected to pin 41 of header 9 of beaglebone black.
- 3.3V power supply has been provided to the other pin of the push button.

Code:

#include <stdio.h> //includes standard I/O header files
#include <iobb.h> //includes GPIO I/O header files
#include <unistd.h> //includes POSIX API library for adding delay in operation
#define Buzzer 9,23 //pin 23 of header 9
#define PushButton 9,41 //pin 41 of header 9
#define IRbtwnDoor 8,7 //pin 7 of header 8
int main(void) // main function
{
iolib_init(); // initializing GPIO I/O library
iolib_setdir(IRbtwnDoor, DigitalIn); //setting GPIO pin of IR sensor for input
iolib_setdir(Buzzer, DigitalOut); //setting GPIO pin of Buzzer
iolib_setdir(PushButton, DigitalIn); //setting GPIO pin of push button for input
while(1) //continuous loop
{
if (is_high (IRbtwnDoor)) //if pin 7 of header 8 is low
{
printf("Door Closed \n"); //print on terminal
pin_low(Buzzer); // Buzzer remains disabled
usleep (1200000); //delay operation
}
if (is_low (IRbtwnDoor)) //if pin 7 of header 8 is high
{
printf("Obstacle \n"); //print on terminal
pin_high(Buzzer); // Buzzer will be enabled
usleep (1200000); //delay operation
if (is_high (PushButton)) //when button is pressed
{
printf("Buzzer is off \n"); //print on terminal
pin_low(Buzzer); //Buzzer will be disabled
usleep (1200000); //delay operation
} } }
iolib_free(); //end of program (free library resources)
return(0); //return a value
}

- Interfacing Button with BBB

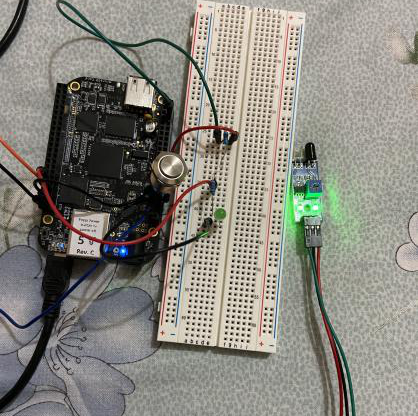
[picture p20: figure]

Fig.5.8 Interfacing of Button with BBB

Above figure shows the interfacing of the push button with BBB along with the IR sensor and LED. The hardware connections of this interfacing are explained below:

Push Button with Beaglebone Black:

- One pin of the push button has been connected to pin 41 of port 9 (P9.41) of Beaglebone Black.
- The resistor of 10K has been connected in between push button and Beaglebone Black.
- The 3.3V power supply has been connected to the other pin of the push button.

Connections of Beaglebone Black with LED:

LED has been connected to the beaglebone black for the demonstration.

- The positive(+) pin of LED has been connected to pin 12 of port 8(P8.12) of beaglebone black.
- The negative (-) pin of the LED has been grounded.

Connection of IR sensor and Beaglebone Black:

- The output pin of IR Sensor is connected to pin 7 of header 8 (P8.7) of beaglebone black.
- The 5V power supply is connected to the Vcc pin of the IR sensor.
- Both GND pins of the IR sensor and beaglebone black are connected to each other.

Code:

#include <stdio.h> //includes standard I/O header files
#include <iobb.h> //includes GPIO I/O header files
#include <unistd.h> //includes POSIX API library for adding delay in operation
#define GreenLED 8,12 //pin 12 of header 8
#define PushButton 9,41 //pin 41 of header 9
#define IRbtwnDoor 8,7 //pin 7 of header 8
int main(void) // main function
{
iolib_init(); // initializing GPIO I/O library
iolib_setdir(IRbtwnDoor, DigitalIn); //setting GPIO pin of IR sensor for input
iolib_setdir(GreenLED, DigitalOut); //setting GPIO pin of LED
iolib_setdir(PushButton, DigitalIn); //setting GPIO pin of push button for input
while(1) //continuous loop
{
if (is_high (IRbtwnDoor)) //if pin 7 of header 8 is low
{
printf("Door Closed \n"); //print on terminal
pin_low(GreenLED); // LED will not glow
usleep (1200000); //delay operation
}
if (is_low (IRbtwnDoor)) //if pin 7 of header 8 is high
{
printf("Obstacle \n"); //print on terminal
pin_high(GreenLED); // LED will glow
usleep (1200000); //delay operation
if (is_high (PushButton)) //when button is pressed
{
printf("Buzzer is off \n"); //print on terminal
pin_low(GreenLED); // LED will not glow
usleep (1200000); //delay operation
} } }
iolib_free(); //end of program (free library resources)
return(0); //return a value
}

- Interfacing Arduino with BBB

Fig.5.9 Interfacing of Arduino with BBB

Above figure explains the hardware connections between Arduino and Beaglebone black. In this interfacing, we have connected both the controllers through UART communication protocol. The connections between both the components are explained below:

- Pin 2 of Arduino is connected to the UART4_RXD pin of Beaglebone Black.
- Pin 3 of Arduino is connected to the UART4_TXD pin of Beaglebone Black.
- Ground pin is connected to the ground pin of Beaglebone Black.

Code:

#include <stdio.h> //Standard C input Output Library
#include <unistd.h> //To use functions like File Opening, Closing, sleep etc.
#include <termios.h> // For Seeting up UART communication
#include <fcntl.h> // File control functions like O_RDWR, O_NONBLOCK etc.
#include <string.h> //For String Operations
int main ()
{
char inArray[100]; // declare a char array for receiving data
char outArray[100]; // A char array to store and send data
int file = open("/dev/ttyO4", O_RDWR | O_NONBLOCK);// Open file in Read Write & Non Blocking Mode
if (file > 0)
{ printf("Started UART communication\n");
}
else
{ printf("Some Error Occured\n"); return 0;// Stop the code
}
struct termios uartsetting;
uartsetting.c_cflag = B9600 | CS8 | CREAD; //Set Baudrate, Byte size and Reading enabled uartsetting.c_lflag = ICANON; //Canonical Mode- Input is available line by line
tcsetattr(file,TCSANOW,&uartsetting); //Apply the setting to UART
tcflush(file, TCIOFLUSH); //Flush all Input and Output Data
while(1) // An Infinite Loop
{
outArray[0] = '\0';
strcpy(outArray, "Send Some Message\n"); // Copy a string in char array
write(file, outArray, strlen(outArray)); // Sending message
printf("Data Sent \n");
sleep(1);
int inputNum = read(file,&inArray,100); // Read the input Message
if(inputNum > 0)
{
for(int i=0; i < inputNum; i++)
{ printf("%c",inArray[i]); //print input message byte by byte }
printf("\n");
sleep(1);
} }
close(file); //Close the f1 at last
}

- Interfacing LCD display with Arduino

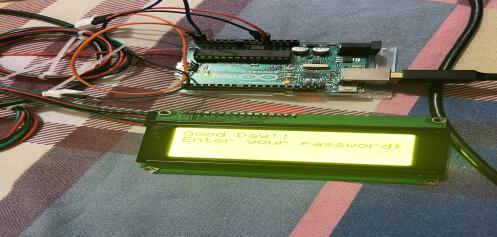
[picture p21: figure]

Fig.5.10 Interfacing LCD display with Arduino

This figure shows the interfacing of LCD display with an Arduino. In our project we are using a LCD Module to display a message to the user while the user wants to open the door manually. The LCD module will display a message, for instance, Enter Your Password. The user will enter the password using the keypad and thus the door will open. However, if the user enters the wrong password the LCD will display another message. This interface will allow the user to open the door manually in case the user does not have the access to their mobile phone. This interfacing makes the project more diverse. The hardware connections between both the components are explained below:

- Vcc pin of lcd is connected to 5v of arduino
- Ground pin of Lcd is connected to ground pin of arduino
- SDA pin of lcd is connected to A4 and SCL to A5

Code:

#include <LiquidCrystal_I2C.h> // Including libraries for the lcd_i2c
#include <LCD03.h> // Including libraries for lcd module
#include "Wire.h" // including libraries for I2C module
//Set the pins on the I2C chip used for LCD connections //ADDR,EN,R/W,RS,D4,D5,D6,D7
LiquidCrystal_I2C lcd(0x27,2,1,0,4,5,6,7);
void setup() // function created to run the code as soon as the arduino is powered up
{
lcd.begin (20,4); // Defining pins of 20 x 4 LCD module
lcd.setBacklightPin(3,POSITIVE); // To set the backlight of the lcd as high
lcd.setBacklight(HIGH); // to set the backlight
lcd.print("Good Day!!"); // this command will print the mentioned text on LCD screen
lcd.setCursor(0,1); // to move to the next line; beacuse lcd has 20 rows and 4 column
lcd.print("Enter your password:"); // this command will print the mentioned text on LCD screen
}
void loop () // the loop function does precisely what its name suggests and loops consecutively allowing your program to change and respond. We use to actively control the arduino board.
{ }

- Interfacing of Arduino with Keypad

Fig.5.11 Interfacing of Arduino with Keypad

In this interfacing, we have used LCD display as well to show the status of the garage door or showing the password. We have used a keypad to enter the password for opening the door. It has 8 terminals, out of 8 four are rows and other four are columns, which we have connected with the Arduino pins.

Code:

#include "Wire.h" // For I2C communication
#include "LCD.h" // For LCD
#include "LiquidCrystal_I2C.h" // For I2C LCD display
#include "Adafruit_Keypad.h" // keypad library for arduino
#define KEYPAD_PID3844 // define the 4x4 matrix keypad
#define R1 5 //connected pin 5 of arduino with pin 1 of ROW1
#define R2 4 //connected pin 4 of arduino with pin 2 of ROW2
#define R3 3 //connected pin 3 of arduino with pin 3 of ROW3
#define R4 2 //connected pin 2 of arduino with pin 4 of ROW4
#define C1 9 //connected pin 9 of arduino with pin 1 of COLUMN1
#define C2 8 //connected pin 8 of arduino with pin 2 of COLUMN2
#define C3 7 //connected pin 7 of arduino with pin 3 of COLUMN3
#define C4 6 //connected pin 6 of arduino with pin 4 of COLUMN4
// leave this import after the above configuration
#include "keypad_config.h" // for keypad configuration
Adafruit_Keypad customKeypad = Adafruit_Keypad( makeKeymap(keys), rowPins, colPins, ROWS, COLS);
LiquidCrystal_I2C lcd(0x27, 2, 1, 0, 4, 5, 6, 7); // 0x27 is the default I2C bus address of the backpack
int max_attempts =3; // define the no. of password attempts
int attempts =0; // initially 0
void setup()
{
Serial.begin(9600); // serial baud rate
customKeypad.begin(); // Set off LCD module
lcd.begin (20, 4); // 20x4 LCD module
lcd.setBacklightPin(3, POSITIVE); // BL, BL_POL
lcd.setBacklight(HIGH); //to set the backlight
lcd.setCursor(0, 0); // setting the writing position
lcd.print(" Welcome to Garage"); // print on the LCD screen
lcd.setCursor(0, 1); // setting the writing position
lcd.print(" Monitoring System."); // print on the LCD
lcd.setCursor(0, 2); // setting the writing position
delay(5000); // delay operation
lcd.clear(); // clear the screen
lcd.setCursor(0,0); // setting the writing position with row and column position
lcd.print("Enter Code:-"); // Enter the password
lcd.setCursor(0, 1); // to move the cursor
lcd.print(" "); // print on LCD
}
char GetKey; //declaration for characters
char KEY[4] = {'1', '2', '3', '4'}; // Array declaration
char Check[4]; int c = 0; // set initial value 0
void loop() // loop begins
if (c == 1) // if integer c is 1
{
lcd.setCursor(0, 1); // first row of lcd
lcd.print(GetKey); // print on the LCD
Check[0] = GetKey; //entered value assigns to the array address 0
}
else if (c == 2)
{
lcd.setCursor(1, 1); // first row second column of lcd
lcd.print(GetKey); // print on LCD
Check[1] = GetKey; // value assign to the array address 1
}
else if (c == 3)
{
lcd.setCursor(2, 1); // first row third column of LCD
lcd.print(GetKey); // print on the LCD
Check[2] = GetKey; // value assign to the array address 2
}
else if (c == 4)
{
lcd.setCursor(3, 1); // first row fourth column of LCD
lcd.print(GetKey); // print on the LCD
Check[3] = GetKey; // value assign to the array address 3
c = 0;
if (Check[0] == KEY[0] && Check[1] == KEY[1] && Check[2] == KEY[2] && Check[3] == KEY[3]) // if entered values are same
{
lcd.setCursor(0, 1);
lcd.print(" ");
lcd.setCursor(0, 2); // second row of LCD
lcd.print("Door Open"); // print Door Open on the LCD
lcd.setCursor(0, 1);
lcd.print(" ");
}
else
{
attempts=attempts+1; // if attempts exceeds more than 3
if (attempts >= max_attempts)
{
lcd.clear(); // clear the LCD
lcd.setCursor(0,2);
lcd.print("Alert send"); // alert notification send
delay(5000); // delay operation
attempts=0;
}
lcd.setCursor(0, 2);
lcd.print("Wrong Password"); // print wrong password
lcd.setCursor(0, 3);
lcd.print("Max 3 attempts"); //print maximum 3 attempts on LCD
delay(5000); // delay operation
lcd.clear();
lcd.setCursor(0,0);
lcd.print("Enter Code:-"); //again ask for password
lcd.setCursor(0, 1);
lcd.print(" ");
} }
customKeypad.tick();
while (customKeypad.available()) // continuous loop begins
{
keypadEvent e = customKeypad.read(); //read the keypad entry
Serial.print((char)e.bit.KEY);
if (e.bit.EVENT == KEY_JUST_PRESSED) // if condition starts
{ Serial.println(" pressed"); // shows pressed status
GetKey = (char)e.bit.KEY; // character key
if (GetKey == 'D') // if key is D (alpha numeric key)
{ lcd.setCursor(0, 3);
lcd.print(" ");
lcd.setCursor(0, 3);
lcd.print("DOOR CLOSING"); // print Door closing on the LCD
delay(2000); //delay operation
lcd.setCursor(0, 3);
lcd.print(" "); }
else c++; }
else if (e.bit.EVENT == KEY_JUST_RELEASED)
Serial.println(" released"); // key released } }

Keypad_config.h // This file contains predefined setup for various Adafruit Matrix Keypads.
#ifndef __KEYPAD_CONFIG_H__
#define __KEYPAD_CONFIG_H__
#if defined(KEYPAD_PID3844)
const byte ROWS = 4; // four rows
const byte COLS = 4; // four columns // define the symbols on the buttons of the keypads
char keys[ROWS][COLS] = {{'1', '2', '3', 'A'}, {'4', '5', '6', 'B'}, {'7', '8', '9', 'C'}, {'*', '0', '#', 'D'}};
byte rowPins[ROWS] = {R1, R2, R3, R4}; // connect to the row pinouts of the keypad
byte colPins[COLS] = {C1, C2, C3, C4}; // connect to the column pinouts of the keypad
#endif
#if defined(KEYPAD_PID1824) || defined(KEYPAD_PID3845) || defined(KEYPAD_PID419)
const byte ROWS = 4; // rows
const byte COLS = 3; // columns // define the symbols on the buttons of the keypads
char keys[ROWS][COLS] = { {'1', '2', '3'}, {'4', '5', '6'}, {'7', '8', '9'}, {'*', '0', '#'}};
byte rowPins[ROWS] = {R1, R2, R3, R4}; // connect to the row pinouts of the keypad
byte colPins[COLS] = {C1, C2, C3}; // connect to the column pinouts of the // keypad
#endif
#if defined(KEYPAD_PID1332)
const byte ROWS = 1; // rows
const byte COLS = 4; // columns // define the symbols on the buttons of the keypads
char keys[ROWS][COLS] = { {'1', '2', '3', '4'}, };
byte rowPins[ROWS] = {R1}; // connect to the row pinouts of the keypad
byte colPins[COLS] = {C1, C2, C3, C4}; // connect to the column pinouts of the keypad
#endif
#endif

- Interfacing Arduino with GSM Module

Fig.5.12 Interfacing Arduino with GSM Module

Above figure shows the interfacing between Arduino and GSM module and also we have connected LCD and Keypad in this interfacing. The purpose of this interfacing is to send an alert message to the owner through the GSM module if an unknown person attempts to access the site by entering the wrong password more than three times.

Connections between Keypad and Arduino:

- C1 to C4 pins of keypad connected to A0 to A4 of Arduino
- R1 pin connected to Pin 8 of Arduino
- R2 pin connected to Pin 9 of Arduino
- R3 pin connected to Pin 12 of Arduino
- R4 pin connected to Pin 13 of Arduino

Connections between LCD and Arduino:

- Vcc -> Vin of Arduino
- Gnd -> Gnd of Arduino
- Scl -> A5 pin of Arduino
- Sda -> A4 pin of Arduino

Connections between GSM module and Arduino

- Vin ----> 5V of Arduino
- Tx -----> Pin 10 of Arduino
- Rx -----> Pin 11 of Arduino
- Gnd ---> Gnd pin of Arduino

Code:

#include <Wire.h>
#include <LiquidCrystal_I2C.h>
#include <Keypad.h>
#include <SoftwareSerial.h>
SoftwareSerial mySerial(10, 11); // RX, TX
const byte ROWS = 4; //four rows
const byte COLS = 4; //three columns
char keys[ROWS][COLS] = { {'1','2','3','A'}, {'4','5','6','B'}, {'7','8','9','C'}, {'*','0','#','D'} };
byte rowPins[ROWS] = {4,5,6,7}; //connect to the row pinouts of the keypad
byte colPins[COLS] = {8,9,12,13}; //connect to the column pinouts of the keypad
byte rowPins[ROWS] = {8,9,12,13}; //connect to the row pinouts of the keypad
byte colPins[COLS] = {A0,A1,A2,A3}; //connect to the column pinouts of the keypad
Keypad keypad = Keypad( makeKeymap(keys), rowPins, colPins, ROWS, COLS );
LiquidCrystal_I2C lcd(0x27,16,2); // set the LCD address to 0x27 for a 16 chars and 2 line display
String password = "2356"; // set password
String message = "Many Wrong Password Retries";
String number = "+16478075601"; // number set for GSM notifications
int sendsms; //Initializing an integer variabe sendsms
String input; //initializing a string variable
void setup()
{
Serial.begin(9600); //Begin the host machine communication at baud rate 9600
mySerial.begin(9600); //Begin the Arduino communication at Baud rate 9600
Serial.println("STARTING");// Print starting on the serial monitor
lcd.init(); // initialize the lcd // Print a message to the LCD.
lcd.backlight();
lcd.clear(); // clear the LCD screen
lcd.setCursor(0,0); // Set cursor at 0,0
lcd.print("STARTING"); //Print STARTING on LCD
Serial.println("Initializing GSM"); //Print Initializing GSM on serial monitor
delay(5000); // Boot Up time for GSM
Serial.println("STARTED\n\n"); //Print STARTED on the serial monitor
Serial.println("\n\n\n"); // leave three lines
lcd.clear(); // for clearing LCD
lcd.setCursor(0,0);// set the LCD cursor to 0,0 and print ENTER PASSWORD
lcd.print("ENTER PASSWORD"); //Print ENTER PASSWORD on LCD screen
lcd.setCursor(0,1);// Set the LCD cursor to 0,1
lcd.print(input);// Print the input from the user
}
void loop()
{
char key = keypad.getKey(); //Get the input from the pressed key
if (key) { Serial.println(key); // If it is a key, print on the LCD
if(key != 'C' and key != 'D')//If the key is not C or D
{ input += key; // Store the pressed key as Input= Input+Key }
else if(key == 'C')// If the pressed Key is C, Delete the last pressed key
{ input = input.substring(0,input.length()-1); }
else if(key == 'D') //If the pressed key is D, Check whether it matches with the password
{ if(input == password) //Checking whether Input is same as set password
{ Serial.println("Right Password");// If yes print Right Password on serial monitor
lcd.setCursor(0,1); // Set LCD cursor to 0,1
lcd.print("CORRECT PASSWORD . ");// If yes print Correct password on LCD screen
sendsms = 0; // For correct password sendsms=0 }
else { Serial.println("Wrong Password"); //If input is not equal to set password, Print wrong password on the serial monitor
lcd.setCursor(0,1);//set LCD screen to 0,1
lcd.print("WRONG PASSWORD X ");// Print WRONG PASSWORD on the LCD screen as well
Sendsms++; //In this case sendsms= sendsms+1 }
delay(2000);//Give delay
input = "";

if(sendsms >= 3)//if sendsms >=3 the GSM module will be activated
{ lcd.setCursor(0,1);//set the LCD cursor to 0,1
lcd.print("X SENDING SMS X ");//print SENDING SMS on the LCD screen
SMS();//Send SMS
sendsms = 0; // once an sms is sent set the sendsms to 0 } }
Serial.print("Input: "); //print Input on the serial monitor
Serial.println(input);// receive that input and print it on the monitor
lcd.setCursor(0,1);// setthe LCD cursor to 0,1
lcd.print(input); //print the user input on the LCD screen
lcd.print(" ");//then print space }
delay(20);// give delay }
int SMS() //function for sending sms
{ Serial.print("Sending SMS to : "); //print it on serial monitor
Serial.println(number); //print the number on serial monitor
mySerial.println("AT+CMGF=1"); //Sets the GSM Module in Text Mode
delay(200);
//Serial.println ("Set SMS Number");
mySerial.println("AT+CMGS=\"" + number + "\"\r"); //Mobile phone number to send message
delay(200);
String SMS = "Many Wrong Password Retries";
mySerial.println(SMS);
delay(100);
mySerial.println((char)26);// ASCII code of CTRL+Z
delay(200);
return 0;
}

Coding

#include <iobb.h>
#define GreenLED 8,16
#define RedLED 8,15
#define Right 8,17
#define Left 8,18
#define DoorStatus2ESP 8,10
#define GarageStatus2ESP 8,9
#define DoorOpen4mESP 8,14
#define DoorClose4mESP 8,11
#define IRbtwnDoor 8,7
#define IRoccupancy 8,8
#define LMcheckDoorOpened 9,30
#define LMcheckDoorClosed 9,12
#define DoorOpen4mArduino 9,25
#define DoorClose4mArduino 9,27
#define Buzzer 9,23
#define PushButton 9,41

void CloseDoor()
{
pin_high(Left);
pin_low(Right);
while(is_high(LMcheckDoorClosed))
{
if(!is_high(IRbtwnDoor))
{
pin_low(Left);
pin_low(Right);
pin_high(Buzzer);
}
else
{
pin_high(Left);
pin_low(Right);
}

if(is_low(PushButton))pin_low(Buzzer);
}
pin_low(Left);
pin_low(Right);
pin_high(GreenLED);
pin_low(RedLED);
pin_low(Buzzer);
pin_low(DoorStatus2ESP);
}
void OpenDoor()
{
pin_high(Right);
pin_low(Left);
pin_high(Buzzer);
while(is_high(LMcheckDoorOpened))
{
if(!is_high(IRbtwnDoor))
{
pin_low(Left);
pin_low(Right);
pin_high(Buzzer);
}
else
{
pin_high(Right);
pin_low(Left);
}

if(is_low(PushButton))pin_low(Buzzer);

}

pin_low(Right);
pin_low(Left);
pin_high(RedLED);
pin_low(GreenLED);
pin_low(Buzzer);
pin_high(DoorStatus2ESP);
}

int
main(void)
{

iolib_init();
iolib_setdir(GreenLED, DigitalOut);
iolib_setdir(RedLED, DigitalOut);
iolib_setdir(Right, DigitalOut);
iolib_setdir(Left, DigitalOut);
iolib_setdir(DoorStatus2ESP, DigitalOut);
iolib_setdir(GarageStatus2ESP, DigitalOut);
iolib_setdir(Buzzer, DigitalOut);
iolib_setdir(DoorOpen4mESP, DigitalIn);
iolib_setdir(DoorClose4mESP, DigitalIn);
iolib_setdir(IRbtwnDoor, DigitalIn);
iolib_setdir(IRoccupancy, DigitalIn);
iolib_setdir(LMcheckDoorOpened, DigitalIn);
iolib_setdir(LMcheckDoorClosed, DigitalIn);
iolib_setdir(DoorOpen4mArduino, DigitalIn);
iolib_setdir(DoorClose4mArduino, DigitalIn);
iolib_setdir(PushButton, DigitalIn);
iolib_delay_ms(500);
//CloseDoor();

while(1)
{

if(is_high(DoorOpen4mArduino) || is_high(DoorOpen4mESP))
{
OpenDoor();
}
else if(is_high(DoorClose4mArduino) || is_high(DoorClose4mESP))
{
CloseDoor();
}

if(is_low(IRoccupancy)) pin_high(GarageStatus2ESP);
else pin_low(GarageStatus2ESP);

}
iolib_free();
return(0);
}

Autorun Program:

1. Find the location of object file of Garagedoor using command pwd
2. I get location as home/debian/GarageDoor
3. Run command - sudo nano /lib/systemd/system/autostart.service
4. Add this to nano terminal --scripted file for autorun

[Unit]
Description=Service File to start the GarageDoor File
After=syslog.target network.target
[Service]
Type=simple
ExecStart=/home/debian/GarageDoor
[Install]
WantedBy=user.target

Ctrl+o enter ctrl+X

5 run command- sudo systemctl enable autostart.service

6. Sudo reboot

Final Model

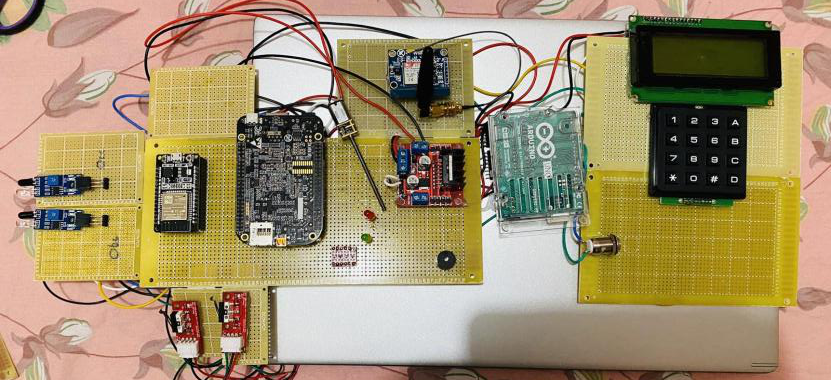
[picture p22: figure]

Fig.5.13 Connections of Hardware components

Fig.5.14 Backview of the project

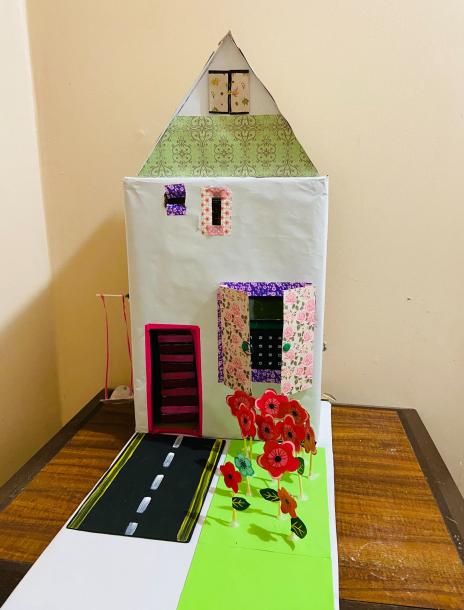
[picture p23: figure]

Fig.5.15 Final model of our project

Output Link:

https://www.youtube.com/watch?v=AJK3sm6TUy4

Chapter VI

Evaluation

Introduction

This chapter will discuss the various issues while selecting the hardware components and connecting them with other components for transferring the data or getting the output. Finally, the chapter will go on discussing methods of solving discrepancies or issues related to Beaglebone Black, IR Sensor, GSM Module and Cloud Service (ThingSpeak).

Minimum Requirements

Minimum project requirements will be running the IOT based smart garage door system on Linux and getting the output. Also, another task is to inform the owner through GSM module if anyone tries to open the garage through keypad by entering the wrong password more than three times. While updating the user about the activity via GSM based SMS the system must be capable to get the data updated to the cloud service. As the last requirement the system must be running without the help of any laptop or other devices.

Troubleshooting

This section of the chapter will tell you about the various we faced during the entire course of the project. The issues and their solutions are as follows:

- Getting the hardware ready was a problem as some of the GSM may or may not be compatible with the Beaglebone and since this was the first time, we were using GSM thus we had some confusion. To resolve this issue, we had to search many issues and thus after looking at the links we found that either SIM900 or SIM800 would be compatible thus we used SIM800.
- While cloning a git repository for GPIO library. I forget to connect the BBB to the internet via ethernet cable.
- While writing c code. The output is shown as continuous flow on the terminal.
- Use POSIX API library to add delay during suspending operations
- The LED was not glowing at first as I connected it to pin 11 of header P8 but after changing it to pin 12 of header P9 it started glowing.
- In c programming while defining LED pins I defined it as “#define LEDpin 12,8” i got error “segmentation fault”. then I changed it to “#define LEDpin 8,12”
- When I ran my code on bbb the DC motor did not start. Because the connections were loose. I made the connections again and then it ran successfully.
- While writing the code It was difficult for me to understand the logic of the IR sensor. Hence when I initially wrote the code the logic was opposite. But eventually it turned out as it was meant to be.
- Another issue we faced related to the cloud service, whenever we were checking that the data was getting up to the cloud but was not unable to get it displayed then we checked that we had few spelling errors and after that we corrected all the spellings and we could see the data on the cloud.

Chapter VII

Conclusion

Future Work

- We cannot reset the password directly from the keypad, for that we need to do modifications in the code.
- Also, in future use of a camera can also enhance the security feature, like by capturing the vehicle number’s pictures we can save them on the cloud for future use if something happens.
- We design this project only for single garage door, we cannot use this project for multiple garage doors.
- For the wifi connection, we have to add the network credentials in the code, we cannot use any random network for connecting to the cloud.
- This project lacks the feature of LCD lock, like if someone enters the incorrect password more than three times then, automatically the LCD screen will be locked.

Chapter VIII

User’s Guide

About the Product

The product is a smart garage door monitoring system which can be a great feature to your normal garage doors. The system will provide various services to you like accessing the garage door both through webpage as well as with keypad and LCD. Also the information of opening and closing of the garage door will be stored on cloud service called Thingspeak. As a security feature the notification of opening and closing of the garage door is being sent to the user and if anyone enters the wrong password more than 3 times then also the user will get notified.

Powering Up the System

To power up the system you will require a power adaptor of 5V, 2A. The power adaptor will be used to power up the Beaglebone Black which is the main microcontroller unit of the product. When it gets powered ON the top LEDs must start blinking in a repeated motion. The Beaglebone Black will provide power to all the other components of the product.

Fig.8.1. Beaglebone with Adapter

Connecting Wifi

When using the product for the first time we need to connect it to the preferred wifi network. To provide wifi service we are using ESP32 wifi module which provides the internet service to the product.

Make sure that you have a strong and preferable wifi network.

To connect to the wifi network make sure you provide the correct SSID and Wifi password into the code to upload to ESP32 wifi module.

(a) (b)

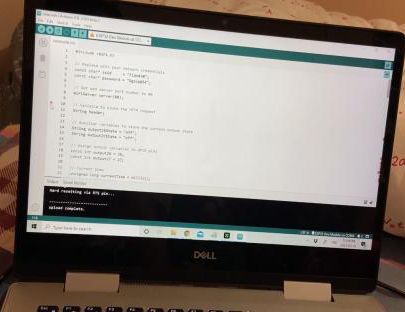
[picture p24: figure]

(c) (d)

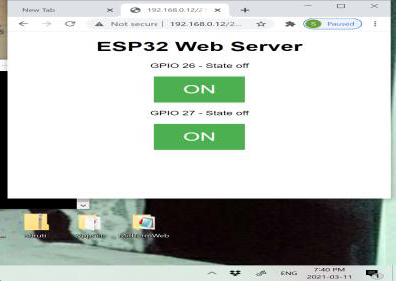
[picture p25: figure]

Fig.8.2(a) Uploading Code to Wifi Module; (b) Connecting Wifi to the Wifi Module; (c) Wifi Getting Connected; (d) ESP32 Web Server

Connecting to Web Platform

We are using Thingspeak.com as a cloud service platform.

- The link to the thingspeak account is: https://thingspeak.com/channels/1320865/.
- This link can be shared among the users to get the live updates of the garage door status and how many times the door has been accessed.
- The main features of this cloud service are: a) It can show the live status of the door from anywhere. b) The status is in the graph format in three different charts which represents how many times the door has been opened or closed and the status of the garage whether it is vacant or occupied. c) It represents the data very clearly and specifically.

Fig 8.3. Cloud Service Thingspeak Page

Manual Operation of Garage Door

This product can also be accessed manually as it has been provided with keypad and LCD access as well. When the power has been provided to the LCD screen it will show “Welcome to Garage Monitoring System” and then it will ask you to “Enter Password”. Then you can use the keypad to enter the password which is “1234”. As you will enter the correct password the garage door will automatically open.

To close the door just press the “D” key on the keypad and the door will automatically get closed.

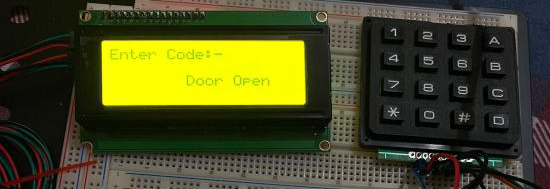
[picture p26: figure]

Fig.8.4. Keypad and LCD

Accessing Pushbutton

There is one pushbutton with the product. The use of the pushbutton is to disable the buzzer. The buzzer provided in the product will get enabled and starts making noise whenever any obstacle comes in between the door while closing it. So you can just press the push button to disable the buzzer.

References

1. Retrieved from IoTDesignPro (2019, Nov 07) IoT Wi-Fi Garage Door Opener using NodeMCU ESP12E https://iotdesignpro.com/projects/iot-based-garage-door-opener
2. Retrieved from PROJECT HUB (2018, Oct 27) RFID and Keypad Based Door Lock Using Arduino https://create.arduino.cc/projecthub/muhammad-aqib/rfid-and-keypad-based-door-lock-using-arduino-89e1d5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
3. Retrieved from Robu.in, Tuesday May19,2020, Priyanka D. URL: https://robu.in/ir-sensor-working/
4. Retrieved from IndustrialShields.com, 2020, URL:https://www.industrialshields.com/blog/arduino-industrial-1/post/how-to-use-the-gprs-module-sim800l-library-129
5. Retrieved from Cuidevices.com, basics technologies and buzzers and tone driving circuits, Bruce R,2021 URL:https://www.cuidevices.com/blog/buzzer-basics-technologies-tones-and-driving-circuits
6. Retrieved from Lastminuteengineers.com, Arduino keypad tutorial, 2021, URL: https://lastminuteengineers.com/arduino-keypad-tutorial/
7. Retrieved from lastminuteengineers.com L298N with DC Motor ,2021 https://lastminuteengineers.com/l298n-dc-stepper-driver-arduino-tutorial/
8. Retrieved from thomas.net, Instruments control limit switches, 2021 URL: https://www.thomasnet.com/articles/instruments-controls/limit-switches/
9. Retrieved from Instructables.com, interfacing lcd 20*4 display with Arduino,URL: https://www.instructables.com/Interfacing-20x4-LCD-with-Arduino/
10. Retrieved from Industrialshields.com, module esp32, 2020, URL: https://www.industrialshields.com/blog/arduino-industrial-1/post/wifi-bluetooth-module-esp32-133
11. Retrieved from Cuidevices.com, basics technologies and buzzers and tone driving circuits, Bruce R,2021 URL:https://www.cuidevices.com/blog/buzzer-basics-technologies-tones-and-driving-circuits
12. Retrieved from TEPTechnopreneur (2016, Nov 13) 6 Necessary Embedded Tools URL:https://www.theengineeringprojects.com/2016/11/necessary-embedded-tools.
13. Retrieved from educba.com, What is eclipse IDE? URL:https://www.educba.com/what-is-eclipse-ide/
14. Retrieved from filehippo.com(2019, Jan 30) URL:https://filehippo.com/download_tera_term/?ex=CORE-190.2
15. Retrieved from github.com (2020, Sept 24) URL:https://github.com/arduino/arduino-pro-ide
16. Retrieved from geeksforgeeks.org (2019, Aug 26) Difference between Compiler and assembler URL:https://www.geeksforgeeks.org/difference-between-compiler-and-assembler/
17. Retrieved from geeksforgeeks.org(2019, Nov 21) Linker URL:https://www.geeksforgeeks.org/linker/
18. Retrieved from electronics-notes.com, USB operation: Protocol, Data transfer & packets https://www.electronics-notes.com/articles/connectivity/usb-universal-serial-bus/protocol-data-transfer.php
19. Retrieved from teachmemicro.com, BEAGLEBONE BLACK SERIAL CONNECTION TO ARDUINO https://www.teachmemicro.com/beaglebone-black-serial-arduino/
20. Retrieved from Trevors Electronic Blog, How to get serial UART port working on the beaglebone black. https://electronics.trev.id.au/2018/02/09/get-uart-serial-ports-working-beaglebone-black/
21. Retrieved from electronics-lab.com, Using a 20*4 I2C Character LCD With Arduino UNO https://www.electronics-lab.com/project/using-20x4-i2c-character-lcd-display-with-arduino-uno/
22. Retrieved from robu.in(2020, Jan 9), Interfacing Sim 800L with Arduino. https://robu.in/sim800l-interfacing-with-arduino/
23. Retrieved from github.com(2020, Nov 17), Arduino-SIM800L- driver https://github.com/ostaquet/Arduino-SIM800L-driver
24. Retrieved from electronicwings.com, 4*4 Keypad interfacing with Arduino Uno https://www.electronicwings.com/arduino/4x4-keypad-interfacing-with-arduino-uno
25. Retrieved from instructables.com, Connect ESP32 to AskSensors over https, https://www.instructables.com/How-to-Connect-an-ESP32-to-the-IoT-Cloud/
26. Retrieved from derekmolloy.ie, Writing a Kernel Linux module- Part 3: Buttons and LED URL: http://derekmolloy.ie/kernel-gpio-programming-buttons-and-leds/
27. Retrieved from beagleboard.org (2016,June 5) URL: https://beagleboard.org/p/hoffmanjon/controlling-a-motor-with-an-h-bridge-fd13b2
28. Retrieved from, learn.adafruit.com, Using an ir sensor URL:https://learn.adafruit.com/ir-sensor/using-an-ir-sensor
29. Retrieved from instructables.com (2018, May 6) ESP32: Internal Details and Pinout https://www.instructables.com/ESP32-Internal-Details-and-Pinout/
30. Retrieved from, Perforce.com (2021), MISRA C and MISRA C++ https://www.perforce.com/resources/qac/misra-c-cpp#why
31. Retrieved from, w3schools.com, HTML Introduction https://www.w3schools.com/html/html_intro.asp
32. Retrieved from, educba.com, Versions of HTML https://www.educba.com/versions-of-html/
33. Retrieved from Components101.com, L298N Motor Driver(2020, April13) https://components101.com/modules/l293n-motor-driver-module
34. Retrieved from, ThingSpeak https://thingspeak.com/
35. Retrieved from, Code Project, An Introduction to Thingspeak https://www.codeproject.com/Articles/845538/An-Introduction-to-ThingSpeak
36. Retrieved from, MDN Web Docs, An Overview of HTTP https://developer.mozilla.org/en-US/docs/Web/HTTP/Overview
37. Retrieved from, Webopedia https://www.webopedia.com/definitions/802-11/
38. Retrieved from, MQTT.org https://mqtt.org/
39. Shabaz (2019,August 14) Element14.com Retrieved from https://www.element14.com/community/community/designcenter/single-board-computers/next-genbeaglebone/blog/2019/08/15/beaglebone-black-bbb-io-gpio-spi-and-i2c-library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
40. Retrieved from, randomnerdtutorial.com https://randomnerdtutorials.com/esp32-web-server-arduino-ide/
41. Retrieved from IoT Design Pro https://iotdesignpro.com/projects/how-to-send-data-to-thingspeak-cloud-using-esp32
42. Arduino lesson- IR obstacle Avoidance sensor, Osoyoo (2017,july 21). Retrieved from https://osoyoo.com/2017/07/24/arduino-lesson-obstacle-avoidance-sensor/
43. Usleep Linux manual page (2017,September 15) Retrieved from https://man7.org/linux/man-pages/man3/usleep.3.html
44. Monk S. (2021) Blinking an LED with BeagleBone Retrieved from https://learn.adafruit.com/blinking-an-led-with-beaglebone-black/writing-a-program
45. Retrieved from, EasyEDA https://docs.easyeda.com/en/FAQ/Editor/index.html
46. Retrieved from, twistedtraces.com https://www.twistedtraces.com/blog/learn-about-different-types-of-pcbs-and-their-advantages
47. Retrieved from, vse.com

https://www.vse.com/blog/2019/10/29/gerber-files-explained-understanding-their-role-in-pcb-manufacturing/

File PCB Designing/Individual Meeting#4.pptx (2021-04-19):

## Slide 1

IOT Based Garage Door Opener
Presented by: Manpreet Kaur
C0757604
Group 4

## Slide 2

Designing PCB and Creating Gerber Files

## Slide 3

Content:
- Importance of PCB Designing in this project
- Introduction to PCB Designing
- Types of PCB
- EasyEDA Software : Features, Usage
- Troubleshooting
- Conclusion
- References

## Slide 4

Importance of PCB designing in our project
The Printed Circuit board is very important in all electronic gadgets.which are used either for domestic use, or for industrial purpose. PCB design services are used to design the electronic circuits. Apart from electrically connecting, it also gives mechanical support to the electrical components. We are also using various components in our project for which we need PCB board and therefore PCB designing is important. In this presentation, I will discuss how achieved this goal of my project.

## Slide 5

PCB designing: Introduction
A printed circuit board is a rigid structure that contains electrical circuitry made up of embedded metal wires called traces, and larger areas of metal called planes. Electronic components are soldered to the top, bottom, or both layers of the board onto metal pads. These pads are connected to the board circuitry allowing the components to be interconnected together. The board may be composed of either a single layer of circuitry, circuitry on the top and bottom, or of multiple layers of circuitry stacked together.

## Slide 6

PCB designing : Types
- Single side PCBs: Single sided PCBs are the basic type of circuit boards, which contain only one layer of substrate or base material. The layer is covered with a thin layer of metal, i.e. copper- which is a good conductor of electricity.
- Double Sided PCBs: Double sided PCBs have both the sides of the substrate featuring metal conductive layer. Holes in the circuit board allow the metal parts to be attached from one side to the other. These PCBs connect the circuits on the either side by either of the two mounting schemes, namely through-hole technology and surface mount technology.

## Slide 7

PCB designing : Types
- Multilayer PCBs: Multi-layer PCBs are printed circuit boards, which comprise more than two copper layers like 4L, 6L, 8L, etc. These PCBs expand the technology used in double sided PCBs.
- Rigid PCBs: Rigid PCBs refer to those types of PCBs whose base material is fabricated from a solid material and which cannot be bent.
- Flexible PCBs: Flexible PCBs are constructed on a flexible base material. These PCBs come in single sided, double-sided and multilayer formats. This helps in reducing the complexity within the device assembly.

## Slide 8

PCB designing : Types
- High Frequency PCBs: High-frequency PCBs are used in the frequency range of 500 MHz – 2 GHz. These PCBs are used in various frequency critical applications like communication systems, microwave PCBs, microstrip PCBs, etc.
- Aluminium Backed PCBs: These PCBs are used in high power applications, as the aluminum construction helps in heat dissipation.

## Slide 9

EasyEDA: Introduction
EasyEDA is a web-based EDA
tool suite that enables hardware engineers
to design, simulate, share - publicly
and privately - and discuss schematics,
simulations and printed circuit boards.
Registered users can download
Gerber files from the tool free of
charge; but for a fee, EasyEDA offers
a PCB fabrication service.


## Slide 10

EasyEDA : Features
- Simple, Easier, Friendly , and Powerful General drawing Capabilities.
- Schematic Capture.
- PCB Layout and Gerber Files.
- Working Anywhere, Anytime and Any Device.
- Real- Time team cooperation.
- Sharing Online.
- Integrated PCB Fabrication.
- Direct links to LCSC Components for selection.

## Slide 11

Gerber Files:
Gerber files are open ASCII vector format files
that contain information on each physical
board layer of your PCB design. Circuit board
objects,like copper traces, vias, pads, solder
mask and silkscreen images, are all represented
by a flash or draw code, and defined by a series
of vector coordinates. These files are used by
PCB manufacturers to translate the details
of your design into the physical properties
of the PCB.


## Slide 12

EasyEDA: Download
Go to your browser and type this link https://easyeda.com/page/download


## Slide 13

EasyEDA: Usage


Open the sheet with the schematic diagram

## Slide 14

EasyEDA: Usage


Then Go to design and select convert schematic to PCB

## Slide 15

EasyEDA: Usage


Then we put all the components inside the size of PCB Board we selected.

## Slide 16

EasyEDA: Usage


Then we put all the components inside the size of PCB Board we selected.

Choose Auto router

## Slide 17

EasyEDA: Usage


Then we put all the components inside the size of PCB Board we selected.

Then choose Local ; we have install local auto router first

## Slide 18

EasyEDA: Usage


Then we put all the components inside the size of PCB Board we selected.

Click on this link and download zip file; follow the steps mentioned following.

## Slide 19

EasyEDA: Usage


Extract the zip file in the folder on your machine.

Then we put all the components inside the size of PCB Board we selected.

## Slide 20

EasyEDA: Usage


Then we put all the components inside the size of PCB Board we selected.

By Selecting Win64; this window will open

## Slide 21

EasyEDA: Usage


Then we put all the components inside the size of PCB Board we selected.

Local Router is now available

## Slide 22

EasyEDA: Usage


Then we put all the components inside the size of PCB Board we selected.

Select PCB Fabrication (Gerber Files)

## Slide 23

EasyEDA: Usage
EasyEDA provides a real time
DRC(Design Rule Check) function.
This is a big feature of EasyEDA.
Now EasyEDA will let you know
the error in routing. This feature
helps in the better routing of
the circuit.


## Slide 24

EasyEDA: Usage


Then we put all the components inside the size of PCB Board we selected.

Extract Gerber Files; Multiple Gerber files will appear on the screen

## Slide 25

EasyEDA: Usage


Then we put all the components inside the size of PCB Board we selected.

To see Gerber files we need this software; this will allow gerber files to open and check before fabrication on board.

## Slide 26

EasyEDA: Usage


Window will look like this after we open the gerber files

Then we put all the components inside the size of PCB Board we selected.

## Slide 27

Troubleshooting
While making the PCB fabrication, there was some DRC errors because I did not placed all the components in the selected pcb space. Once I did put all the components in that space there were no errors and my pcb layout was fine.
I had to download the gerber view software as well to see the gerber view. Firstly I installed it incorrectly and it was not working. Then I reinstalled and it was working fine.

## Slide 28

Conclusion
The goal to achieve pcb layout and gerber files was achieve by following the steps mentioned in the Earlier slides and this way I was able to do my task for our project.

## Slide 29

References:
Retrieved From: twistedtraces.com URL:https://www.twistedtraces.com/blog/learn-about-different-types-of-pcbs-and-their-advantages
Retrieved From: vse.com
URL:https://www.vse.com/blog/2019/10/29/gerber-files-explained-understanding-their-role-in-pcb-manufacturing/
Easy eda full tutorial
Retrieved from: Youtube
URL:https://www.youtube.com/watch?v=q9fgMhfEzko

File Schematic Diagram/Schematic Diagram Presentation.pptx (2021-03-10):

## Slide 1

Schematic Diagram: IoT based Garage Door Opener
Group 4
Shivinder Kaur
C0751078

## Content:

1. Introduction
2. Tools Required
3. Schematic Diagram
4. Project Schematic
5. Conclusion
6. Reference

## Introduction:

Schematic capture is the process of creating a schematic diagram for an electronic circuit using various tools designed for the job.
It is also known as wiring diagram or circuit diagram.
This can be done from as simple as using a pen and paper to using schematic capture software.
It is a process of designing a circuit that will serve a specific purpose by making use of industry standards and conventions to put the design into a visual state, either via hand drawing or by entering it into a software made for the purpose.

## Introduction:

It can be seen in the same manner as a digital artist might draw using a tool like Photoshop or a writer using a word processor.
In these schematic diagram, we represent actual wiring of the components and represent the proper functioning of the components.
We also able to know what pins we have to use from our main controller.
Example of Schematic Diagram Software: EASY EDA, Fritzing, Proteus, KiCAD EDA, circuit lab etc.

## Tools Required:

- Software Installed: EasyEDA
- Components used:
- Main Processing Unit (BBB) - Primary Device
- Arduino - Secondary Device
- IR Sensor
- GSM Module
- Keypad and LCD
- ESP 32
- L298 Motor Driver and DC gear motor
- Buzzer and Push button

## EasyEDA

For designing our project schematic diagram, we are using EASYEDA schematic diagram software.
EasyEDA is a free open source software which is easy to use and understand.
EasyEDA is a web based Electronic Design Automation tool (EDA). we can use it in browser or also download it software.
The software is compatible with Linux OS, Windows OS and MacOS.
EasyEDA has all the features that we expect and easily take our design from conception through to production.

## EasyEDA


## EasyEDA


## EasyEDA


## EasyEDA


Navigation Panel

Displays all the existing projects

## EasyEDA


All the basic existing components like power supply, ground and other can be found here.

## EasyEDA

We can easily search any component from here and import it to the schematic diagram.

## EasyEDA

These two options take you to the external website if you wish to order any component.

## EasyEDA


We can start our new project by clicking here.

## EasyEDA


Here we can give the title to our project.

## EasyEDA

After creating a project then this sheet window will appear where we can create our schematic diagram.

## EasyEDA

Menu Bar

## EasyEDA

All the components that we will use in the project would be here along with their pin description.

## EasyEDA

These are the wiring tools that we can use while connecting the components with each other.

## EasyEDA

This is the attribute column where we can change names, colour, style, size or etc. about the board.

## EasyEDA

Drawing Sheet Information

## EasyEDA


We can type the component name tha we want to use.

## EasyEDA


When we search the component then the search result will appear as shown in the picture and we can select it by clicking on place and can place it on our sheet.
So, here for the example I have chosen Beaglebone Black; similarly I searched all the components that we required for our project and placed them on the sheet.

## Schematic Diagram


## Schematic Diagram


## Schematic Connections


First we connected the Logic Level Converter to BeagleboneBlack.

Beaglebone Black | Logic Level Converter
P9.25 (GPIO 117) | HV3
P9.27(GPIO 115) | HV4

## Schematic Connections


Then we connected the LV side of Logic Level Converter to Arduino Uno.

Arduino Uno | Logic Level Converter
A1 | LV3
A2 | LV4

## Schematic Connections


Here are the connections of Arduino Uno to LCD Display and Keypad.

Arduino Uno | Keypad
D2 | 1
D3 | 2
D4 | 3
D5 | 4
D6 | 5
D7 | 6
D8 | 7
D9 | 8

## Schematic Connections

Here are the connections of Arduino Uno to LCD Display and Keypad.

Arduino Uno | LCD Display
A4 | SDA
A5 | SCL
5v | 5v
GND | GND

## Schematic Connections


Arduino Uno and GSM SIM800L connections.

Arduino Uno | GSM SIM800L
D12 | Tx
D11 | Rx
5v | 5v
GND | GND

## Schematic Connections


Beaglebone Black and PIR Sensor connections.

PIR Sensor | Beaglebone Black
SIG/OUT | GPIO_66 (P8.7)
VCC | 3V
GND | GND

## Schematic Connections


Beaglebone Black and ESP32 Wifi Module connections.

ESP32 wifi module | Beaglebone Black
D12 | GPIO_68(P8.10)
D13 | GPIO_69(P8.9)
D14 | GPIO_44(P8.12)
D27 | GPIO_45(P8.11)
5V | 5V
GND | GND

## Schematic Connections


Beaglebone Black and Motor Driver connections.

Motor Driver L298N | Beaglebone Black
IN1 | GPIO_20 (P9.41)
IN2 | GPIO_49(P9.23)
5V | 5V (P9.5)
GND | GND

## Schematic Connections

Motor Driver and Motor connections.

Motor Driver L298N | Motor
OUT1 | 2
OUT2 | 1

## Schematic Connections


Beaglebone Black and Limit Switch

Limit switch | Beaglebone Black
LM1 | GPIO_60(P9.12)
LM2 | GPIO_112(P9.30)
GND | GND

## Schematic Connections


Beaglebone Black and LED

LED | Beaglebone Black
White LED | GPIO_47(P8.15)
Green LED | GPIO_46(P8.16)
GND Red Led | GND
GND Green LED | GND

## Schematic Connections


Beaglebone Black and Buzzer

Buzzer | Beaglebone Black
Positive | GPIO_27(P8.17)
GND | GND

## Schematic Connections


Beaglebone Black and Push button

Push Button | Beaglebone Black
Positive | GPIO_65(P8.18)
GND | GND

## Reference

- Retrieved from techopedia, URL: https://www.techopedia.com/definition/21935/schematic-capture
- Retrieved from robotshop, URL: https://www.robotshop.com/community/forum/t/start-your-easy-eda-journey-on-the-free-circuit-design-software/4950
- Retrieved from EasyEDA, URL: https://docs.easyeda.com/en/FAQ/Editor/index.html

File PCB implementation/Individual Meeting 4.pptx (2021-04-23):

## IoT Based Garage Door Opener- Zero PCB Implementation Part-1

Shivinder Kaur (C0751078)
Group 4

## Content:

- Introduction to PCB
- Types of PCBs
- Zero PCB
- Introduction to Soldering
- Steps for Soldering
- Soldering a Circuit Board
- Schematic of Project
- PCB Design of Project
- Requirements

## Content:

- Top View of PCB
- Bottom View of PCB
- Connections Beaglebone Black and IR Sensors
- Connections of BBB and Buzzer
- BBB and LEDs
- BBB and Wifi Module
- BBB and Limit Switches
- Testing Continuity
- References

## Introduction to PCB:

- A printed circuit board (PCB) mechanically supports and electrically connects electrical or electronic components using conductive tracks, pads and other features etched from one or more sheet layers of copper laminated onto and/or between sheet layers of a non-conductive substrate.
- Components are generally soldered onto the PCB to both electrically connect and mechanically fasten them to it.


## Types of PCBs:


- Single sided PCBs
- Double sided PCBs
- Multilayer PCBs
- Rigid PCBs
- Flex PCBs
- Rigid-Flex PCBs
- High Frequency PCBs
- Aluminium Backed PCBs
- Zero PCBs

## Zero PCBs:


- Zero PCB is basically a general-purpose printed circuit board (PCB), also known as perfboard or DOT PCB.
- It is a thin rigid copper sheet with holes pre-drilled at standard intervals across a grid with 2.54mm (0.1- inch) spacing between holes.

## Zero PCBs:

- Each hole is encircled by a round or square copper pad so that component lead can be inserted into the hole and soldered around the pad without short-circuiting the nearby pads and other leads.
- For connecting the lead of component with another lead, solder these together or join these using a suitable conducting wire.


## Introduction to Soldering:


- Soldering is a joining process used to join different types of metals or components by melting solder.
- Solder is a metal alloy usually made of tin and lead which is melted using a hot iron. The iron is heated to temperatures above 600 fahrenheit which then cools to create a strong electrical bond.

## Steps for Soldering:

- Prepare your workbench: Prepare your workspace. Find your soldering iron and your solder wire and then start heating the soldering iron. Also, place your soldering in a holder when not in use.
- Clean the tip: When the iron is hot, the first thing you should is to clean the tip to remove the old solder from it. You can use a wet sponge, a copper scouring pad or something similar.
- Tin the tip: Before you start soldering, you should tin the tip of the soldering iron. Which just means to melt some new solder onto the tip. This makes the tip transfer heat faster and thereby making the soldering easier and faster.


## Soldering a Circuit Board:

- Component Placement: After the component and board have been cleaned, you are ready to place the components onto the board. Unless you circuit is quite simple and only contains a few components, you will probably not be placing all the components onto the board and solder them at once. Most likely you will be soldering a few components at a time before turning the board over and placing more. In general it is best to start with the smallest and flattest components and then work up to the larger components after the small parts are done.
- Apply Heat: Apply a small amount of solder to the tip of the iron. This helps conduct the heat to the component and board, but it is not the solder that will make up the joint. To heat the joint you will lay the tip of the iron so that it rests against both the component lead and board.


## Soldering a Circuit Board:

- Apply Solder to the Joint: Once the component lead and solder pad has heated up, you are ready to apply the solder. Touch the tip of the strand of solder to the component lead and solder pad, but not the tip of iron. If everything is hot enough, the solder should flow freely around the lead and pad.
- Inspect the Joint and Cleanup: Once the joint is made you should inspect it. Check for the cold joints, shorts with adjacent pads or poor flow. If the joint checks out, move on to the next. To trim the lead, use a small set of side cutters and cut the top of the solder joint.


## Schematic of Project:

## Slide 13

## PCB Design of Project:

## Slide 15

## Requirements:

- Zero PCB
- Soldering Iron
- Soldering Wire
- Jumper or Hookup Wires
- Headers
- Multimeter

## Requirements:

- Beaglebone Black
- ESP32 Wifi Module
- IR Sensor
- Buzzer
- LEDs (Green and Red)
- Limit Switches

## Top View of PCB:

## Bottom view of PCB:

## Connections of Beaglebone Black and IR Sensor:

- The output pin of IR Sensor to detect the obstacle has been connected to pin 7 of port 8 of Beaglebone Black.
- 3.3V power has been given to both the sensors and grounds has been given to the ground pin.


## Connections of Beaglebone Black and IR Sensors:


- The output pin of IR Sensor to detect the occupancy of the garage has been connected to pin 8 of port 8 of Beaglebone Black.
- 3.3V power has been given to both the sensors and grounds has been given to the ground pin.

## Connections of BBB and ESP32 Wifi Module:

- Pin 14 of ESP 32 has been connected to pin 14 of port 8 of Beaglebone Black. This pin is used to open the door from webpage.
- Pin 27 of ESP 32 is connected to pin 11 of port 8 of Beaglebone Black to close the door from webpage.
- Pin 13 of ESP 32 is connected to pin 10 of port 8 of Beaglebone Black to indicate the status of garage door.
- 3.3 V power and ground


## Connections of BBB and Buzzer:


- The positive pin of Buzzer has been connected to pin 23 of port 9 of Beaglebone Black.
- The negative pin of buzzer has been given to ground.

## Connections of BBB and LEDs:


- The positive pin of Green LED has been connected to pin 16 of port 8 of Beaglebone Black.
- The positive pin Red LED has been connected to pin 15 of port 8 of Beaglebone BLack.
- The negative pins of both LEDs has been given to ground pin.

## Connections of BBB and Limit Switches:


- Limit Switch 1 has been connected to pin 12 of port 9 of Beaglebone Black.
- Limit Switch 2 has been connected to pin 30 of port 9 of Beaglebone Black.
- And then ground has been provided to both the switches.

## Testing Continuity:

- Continuity is the presence of a complete path for current flow. A circuit is complete when its switch is closed.
- A digital multimeter’s Continuity Test mode can be used to test switches, fuses, electrical connections, conductors and other components. A good fuse, for example, should have continuity.
- A DMM emits an audible response (a beep) when it detects a complete path.
- The beep, an audible indicator, permits technicians to focus on testing procedures without looking at the multimeter display.


## Testing Continuity:

1. Turn the dial to Continuity Test Mode. It will likely share a spot on the dial with one or more functions, usually resistance. With the test probes separated, the multimeter’s display may show OL and Ω.
2. If required, press the continuity button.
3. First insert the black test lead into the COM jack. Then insert the red lead into the VΩ jack. When finished, remove the leads in reverse order; red first, then black.


## Testing Continuity:

4.With the circuit de-energized, connect the test leads across the component being tested. The position of the test leads is arbitrary. Note that the component may need to be isolated from other components in the circuit.
5. The digital multimeter DMM beeps if a complete path (continuity) is detected. If the circuit is open (the switch is in off position), the DMM will not beep.
6. When finished, turn the multimeter OFF to preserve battery life.

## References:

- PCB : Retrieved from en.wikipedia.org, URL: https://en.wikipedia.org/wiki/Printed_circuit_board
- Types of PCB: Retrieved from theengineersprojects.com, URL: https://www.theengineeringprojects.com/2018/03/different-types-of-pcb-printed-circuit-board.html
- Zero PCB: Retrieved from electronicsforu.com, URL: https://www.electronicsforu.com/technology-trends/learn-electronics/veroboard-zero-pcb-difference
- Soldering: Retrieved from twi-global.com, URL: https://www.twi-global.com/technical-knowledge/faqs/what-is-soldering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,create%20a%20strong%20electrical%20bond.

## References:

- Soldering: Retrieved from instructables.com, URL: https://www.instructables.com/Simple-PCB-soldering/
- How to solder: Retrieved from build-electronic-circuits.com, URL: https://www.build-electronic-circuits.com/how-to-solder/
- Testing Continuity: Retrieved from fluke.com, URL: https://www.fluke.com/en-ca/learn/blog/digital-multimeters/how-to-test-for-continuity

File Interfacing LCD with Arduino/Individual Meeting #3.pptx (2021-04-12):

## IOT Based Garage Door Opener

Manpreet Kaur
C0757604
Group 4

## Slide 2

Interfacing of LCD with Arduino UNO

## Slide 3

Content:
- Importance of this Interfacing
- Arduino UNO : Features, Advantages, Pin Diagram
- Introduction to LCD Module
- I2C Backpack
- Hardware Requirements
- Software requirements
- Code Explanation
- Troubleshooting
- Conclusion
- References

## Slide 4
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

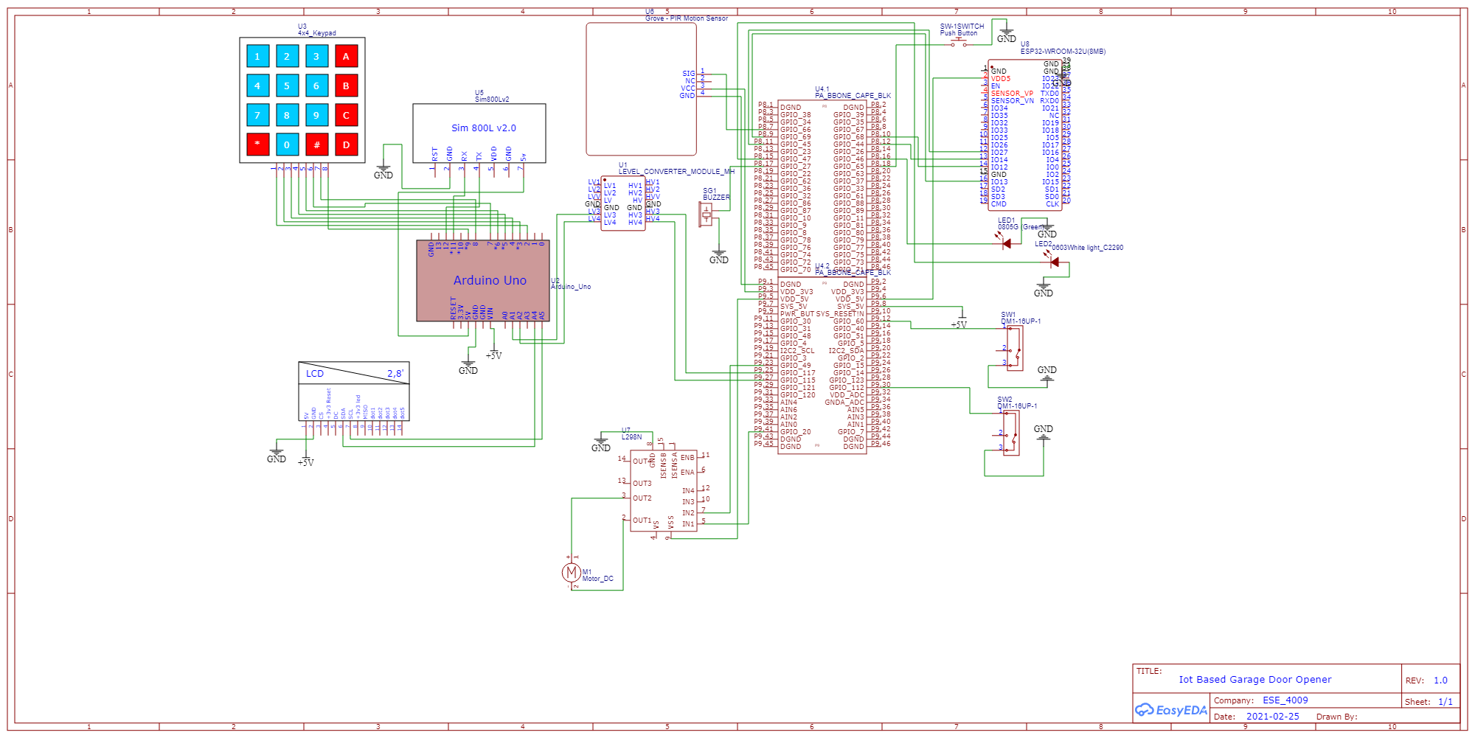
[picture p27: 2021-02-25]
Schematic Diagram/Schematic_IoT based Garage Door Opener_2021-02-25.png

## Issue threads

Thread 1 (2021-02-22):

Testing Components (Part 2)

mikeshams, 2021-02-22:
- Test the motor driver
- Test the GSM module
- Commit to the repository

1511992, 2021-02-23:
> * Test the motor driver
> * Test the GSM module
> * Commit to the reposit

1511992, 2021-02-23:
Hello Professor,
The issues assigned were resolved.

Closed 2021-02-24.

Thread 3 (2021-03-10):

IR Sensor Interface

mikeshams, 2021-03-10:
What issues did you face and how to reslove?

Dawinderkaur, 2021-03-10:
1. While cloning git repository for GPIO library forgets to give ethernet connection to BBB. Error came up as connection failed when i ping google.com
2. I connect the LED pin to pin 11 of the P8 header BBB but it was not glowing as per c code so I replace it with pin 12 of the P8 header.
3. While defining the pin for IR sensor and LED to BBB i define it as “#define LEDpin 12,8” i got error “segmentation fault” . then i changed it to “#define LEDpin 8,12”.so pins are defined as "pin header, pin number"
4. Getting output of c code in continuous flow on terminal. so to make it understand i add some dealy using usleep function in c program.
5. Forget to add POSIX API library at first due to which i get error at usleep function. so i include those library in c program header and error got resolved.

Closed 2021-03-15.

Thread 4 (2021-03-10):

ESP32 Interface

mikeshams, 2021-03-10:
What issues did you face and how to resolve?

ShivinderK, 2021-03-10:
1. With Arduino IDE when I was uploading the code on ESP32 board it was showing error and not getting connected to the board. Then from this link https://randomnerdtutorials.com/installing-the-esp32-board-in-arduino-ide-windows-instructions/, I got to know that while uploading the code I have to the press the boot button and then when it starts showing connecting then release the boot button slowly and it will get connected.

ShivinderK, 2021-03-12:
2. The problem I was getting in the first code was when I was uploading the code to the board it was giving the IP address but the webpage was not opening successfully because of the timeout problem. Then I resolved this issue from this link matlab.com/question/solved-esp32-web-server-drops-connection-crashes/  and then I was able to get the access to the webpage.
3. Then I tested our webpage by connecting the LEDs directly to esp32 board pins 26 and 27 and it successfully giving output by pressing the buttons on webpage.
4. Then I connected the LEDs and esp32 pins to the beaglebone. But the wrong thing I did was the pin that I have to make as an input I made it as output and the output pin as input. So when I was running my code it was not working but it was working when I was connecting the LEDs directly to the esp32. I resolved this issue by defining the pins correctly.
5. Then I was getting problem with if else loop. Then I resolved this issue from this link that how I can properly use the if else loop https://www.programiz.com/c-programming/c-if-else-statement
6. Also while performing I got to know that when I have to upload the code to ESP32, only ESP32 should be connected to the system and not even beaglebone or jumper wires should be connected, otherwise they will create interference while uploading the code to the board.

mikeshams, 2021-03-12:
Do a little research how to check the wifi signal strength using your wifi module?

mikeshams, 2021-03-12:
Do a little research how to check the wifi signal strength using your wifi module?

mikeshams, 2021-03-12:
Do a little research how to check the wifi signal strength using your wifi module?

mikeshams, 2021-03-12:
Do a little research how to check the wifi signal strength using your wifi module?

ShivinderK, 2021-03-12:
7. To check the signal strength I can add this syntax  WiFi.RSSI() and this code provided in this link https://randomnerdtutorials.com/esp32-useful-wi-fi-functions-arduino/  in the program. That will provide the signal strength in he output.

Closed 2021-03-12.

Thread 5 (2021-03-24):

Limit Switch Interface

mikeshams, 2021-03-24:
What issues did you face? How to resolve?

RaghavChopra95, 2021-03-24:
1. In the code I added the delay function but while running the code it was giving error. So I checked it I realized that it requires specific libraries for delay function, so I added the unistd.h library in the code and then I got rid of that error.
2. I made my code with if else statement but there were some errors in that so I improvise the code by using this link https://www.programiz.com/c-programming/c-if-else-statement; this helped me to know how we can properly use the if else statement.
3. While running the code LEDs were not glowing when I was pushing the button of limit switch but was getting output on the terminal. Then I realized that I have used the resistor of high value which was 1K so I changed it to 220 ohm. After that LEDs started glowing too.

Closed 2021-03-24.

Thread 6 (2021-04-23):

PCB Implementation

mikeshams, 2021-04-23:
what issues did you face and how you resolved them?

1511992, 2021-04-23:
1. GPIO Pins of Beaglebone black on header 8 are so close. while soldering it get connected together. it cause short of two pins.
2. after soldering number of components, the tip of soldering iron goes bad. so i have to clean it using flux and sponge.
3. configuring keypad row and column pins correctly with arduino was also hard part.
4. I have to remember all the wiring and connections accurately to make my project work efficiently.
5. Arduino pins were not getting fix on PCB board so i use WiFi Shield board to solder arduino.

Closed 2021-04-23.

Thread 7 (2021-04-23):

PCB Implementation

mikeshams, 2021-04-23:
what issues did you face and how you resolved them?

ShivinderK, 2021-04-23:
1. It was difficult to solder so many components and how to place IR Sensors so that they will detect and work accordingly so I decided to place them on a separate PCB with long wires so that we can place them easily while making the final model.
2. There were so many joints and connections so sometimes they get connected with each other. So I have to desolder the components again and then solder them efficiently so that it will work accurately.
3. I was not much aware of the continuity test with multimeter. So this link https://www.fluke.com/en-ca/learn/blog/digital-multimeters/how-to-test-for-continuity helped me to get aware of the continuity test then I was able to do it.

Closed 2021-04-23.

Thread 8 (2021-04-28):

Plug & Play Mode

mikeshams, 2021-04-28:
How did you make your project in plug and play mode? Explain about the steps you have taken here!

1511992, 2021-04-28:
Plug and Play Mode: Plug and play mode is the mode when the user does not have to install or run manually. The hardware and software  setting is done in such a way that there is no need of external USB Cable for the main microcontroller to run the whole project. Instead, only a power adapter is required to give the supply to the project. In our project, we are powering the whole project by a power adapter directly connect to power socket and our main microcontroller i.e. Beaglebone Black to run the project automatically. When the project will run it will sound a beep after few seconds, which ensures the system is ready to use.

The steps to make the project autorun are as follows:

1.Find the location of object file of Garagedoor using command pwd
2. We get location as home/debian/GarageDoor
3. Run command - sudo nano /lib/systemd/system/autostart.service
4. Add this to nano terminal --scripted file for autorun
[Unit]
 Description=Service File to start the GarageDoor File
After=syslog.target network.target
[Service]
Type=simple
ExecStart=/home/debian/GarageDoor
[Install]
WantedBy=user.target

Ctrl+o   enter ctrl+X

5. run command- sudo systemctl enable autostart.service

6. Sudo reboot

Closed 2021-04-28.

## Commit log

2021-03-10 Create schematic
2021-03-15 Create esp32htmlcode
2021-03-21 Create Interfacing of Beaglebone black with limit switch
2021-04-07 Create Interfacing Beaglebone black with Arduino
2021-04-07 Create ESP32 code
2021-04-19 Create gerber files
2021-04-22 Create PCB
2021-04-30 Create arduino code

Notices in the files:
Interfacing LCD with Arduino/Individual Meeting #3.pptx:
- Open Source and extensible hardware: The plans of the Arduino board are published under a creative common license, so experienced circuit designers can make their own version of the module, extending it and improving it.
